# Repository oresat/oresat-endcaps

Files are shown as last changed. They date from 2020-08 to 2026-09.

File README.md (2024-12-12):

# "End Cap" PCBs for OreSat

These are the "end cap" PCBs that attach to the +Z and -Z ends of the satellites. Mostly these are to protect the end cards from "space", as well as to hold the magnetometers (two per end cap) as far as away from ferrous stuff as possible. It's also a good place for backup antennas, specifically patch antennas (S band and GPS L1).

## Features

- Cutouts for deployable antennas
- Double magnetometers.
- Single vertical 10mm tall 1.27 mm connector that plugs into the "end card" card.
    - On the End Cap:  Harwin M55-6001242R 12 pin female vertical connector 
    - On the End Card below: Harwin M55-7011242R 12 pin male vertical connector
- No available RF connectors.

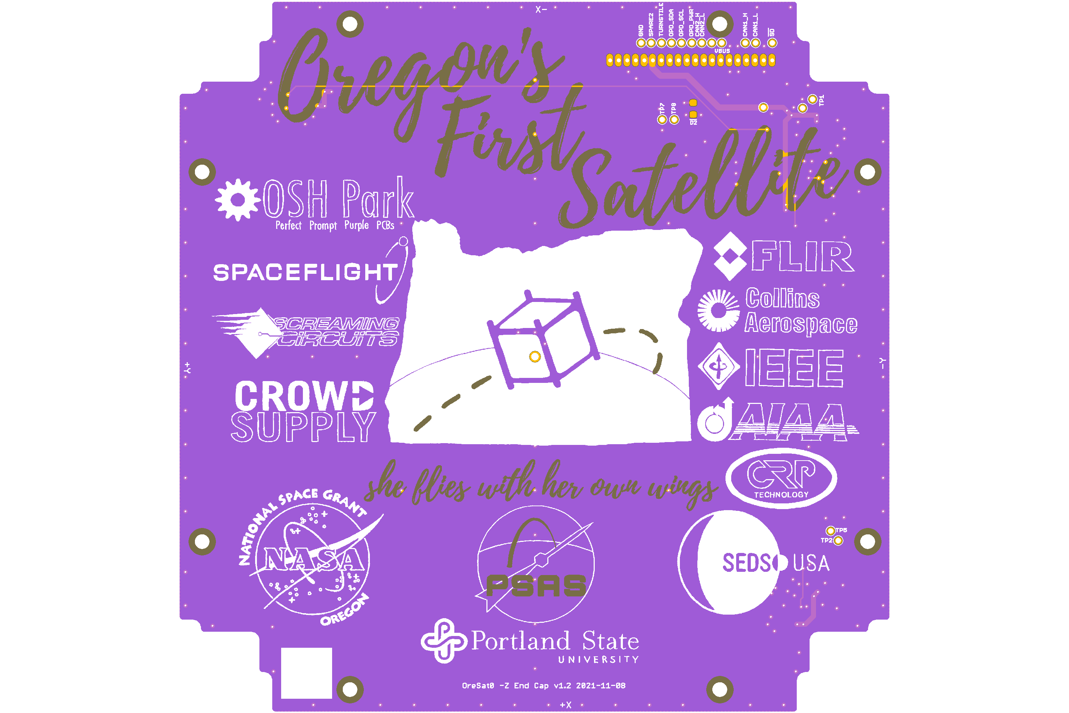
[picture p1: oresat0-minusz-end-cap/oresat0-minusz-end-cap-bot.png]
OreSat +Z End Cap Picture


## LICENSE

Copyright the Portland State Aerospace Society, 2024.

This source describes Open Hardware that is licensed under CERN-OHL-S v2, or any later version.

You may redistribute and modify this source and make products using it under the terms of the CERN-OHL-S v2 (https://ohwr.org/cern_ohl_s_v2.txt).

This source is distributed WITHOUT ANY EXPRESS OR IMPLIED WARRANTY, INCLUDING OF MERCHANTABILITY, SATISFACTORY QUALITY AND FITNESS FOR A PARTICULAR PURPOSE. Please see the CERN-OHL-S v2 for applicable conditions.

Source location: <https://github.com/oresat/>

As per CERN-OHL-S v2 section 4, should You produce hardware based on this source, You must where practicable maintain the Source Location visible on the external case of the Gizmo or other products you make using this source.

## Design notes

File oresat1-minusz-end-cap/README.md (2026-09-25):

---
title: "**OreSat1 -Z End Cap**"
subtitle: |
  **Fabrication and Assembly Information**\
  For build TIME-STAMP
fontsize: 10pt
geometry:
  - margin=0.5in
toc: true
toc-depth: 2
colorlinks: true
urlcolor: blue
---

\newpage

# About this Board

## Board Description

The OreSat1 -Z End Cap is the board that "caps" the -Z end of the OreSat1 satellite. It protects the -Z End Card and also carries two PNI RM3100 magnetometers, as far away from the internal OreSat magnetic noise as possible. 

## Documentation Links

- End cap hardware Git repository: <https://github.com/oresat/oresat-endcap>
- **TODO:** End Cap Design Notes + Design Review Notes

## Documentation Files

| Filename | Notes |
| --- | --- |
| README.pdf | This README file |
| PROJECT-NAME-outline.dxf | Board outline (with holes) in DXF format |
| PROJECT-NAME-pcba.step | 3D model of PCBA (with components) |
| PROJECT-NAME-render-bot.jpg | Render of the top of the 3D model |
| PROJECT-NAME-render-bot.jpg | Render of the bottom of the 3D model |
| PROJECT-NAME-schematic.pdf | PDF of board schematics |

## Contact Information

- Website: <https://www.oresat.org/>
- Email: <oresat@pdx.edu>
- Instagram: @pdxaerospace

## Board Renders

Render of the top of the 3D model
Render of the bottom of the 3D model

\newpage

# Printed Circuit Board (PCB) Fabrication Information

## Board Info

- 4 layer board
- Bounding box is 105.6 x 105.6 mm
- Board thickness is 1.59 mm (0.063 inch)

## Board Requirements

- Design Rules
    - Minimum Trace / Space design rules
       - Outer layers: 0.127 mm (5.0 mil) / 0.127 mm (5.0 mil)
       - Inner layers: 0.127 mm (5.0 mil) / 0.127 mm (5.0 mil)
    - Outer dimension router tolerance: +/- 0.254 mm (10.0 mil)
    - Hole placement tolerance: +/- 0.075 mm (3.0 mil)
    - Inner tab routed slot tolerance: +/- 0.254 mm (10.0 mil)
- Drills
   - Drill Positional Tolerance: 0.051 mm (2.0 mil)
   - Drill Size tolerance: +/- 0.064 mm (2.5 mil)
- Plated/Un-plated holes
  - There are 11 un-plated (NPT) holes
  - PTH minimum diameter: 0.254 mm (10 mil)
  - PTH minimum annulus: 0.102 mm (4 mil) radius
- Outline/Routing
  - Requires a 1.0 mm or smaller diameter routing bit
- Slots
  - There are no slots.
- Cutouts
  - There is one cutout.
- There are 3 fiducials on the top layer and 3 fiducials on the bottom layer.
- Panel tabs ("mouse bites")
   - Card edges must be smooth; no mouse bites or other intrusions into the card outline.
   - If external mouse bites are required, minimize and customer will remove by hand before assembly.
- If not otherwise specified, build to IPC 6012 Class 2 or better.

## Materials

- No controlled impedance.
- Outer layers must be 1 oz Copper, inner layers can be 0.5 or 1.0 oz Copper.
- Isola FR408HR or material recommended.
- Board Surface treatment should be ENIG, althogh immersion Silver is acceptable.
- White silkscreen on top and bottom surface
- Taiyo PSR-4000 or equivalent soldermask on top and bottom, no requirements for color.

## Suggested Stack Up

| Layer | Thickness | Notes |
|---|---|---|
| Top Copper | 0.043 mm /  1.7 mil |  Layer 1 foil, 1 oz Cu after plating |
| prepreg | 0.200 mm /  7.9 mil |  Prepreg - Isola FR408HR 2113 |
| Layer 2 | 0.018 mm /  0.7 mil |  Layer 2 foil, 0.5 oz Cu |
| Core | 0.991 mm / 39 mil |  Core Isola FR408HR |
| Layer 3 | 0.018 mm /  0.7 mil |  Layer 3 foil, 0.5 oz Cu |
| prepreg | 0.200 mm /  7.9 mil |  Prepreg - Isola FR408HR 2113 |
| Bottom Copper | 0.043 mm /  1.7 mil |  Layer 4 foil, 1 oz copper after plating |
| **Total Stackup** | **1.588 mm / 62.5 mil** | |

## Array / Panel Information

- Coordinate with Contract Manufacturer (CM) for optimal size of this panel.
- If no feedback from CM, then produce single boards (no panel).

## Fabrication Files

### IPC-2581 File

| Filename | Notes |
| --- | --- |
| PROJECT-NAME-ipc2581.xml | IPC-2581 board information file |

### Legacy PCB Files

| Filename | Notes |
| ---| --- |
| PROJECT-NAME-Edge_Cuts.gbr | RS274X file for the dimension (outline) layer |
| PROJECT-NAME-F_Silkscreen.gbr | RS274X file for the top silkscreen |
| PROJECT-NAME-F_Mask.gbr | RS274X file for the top soldermask |
| PROJECT-NAME-F_Cu.gbr | RS274X file for the top copper layer |
| PROJECT-NAME-In1_Cu.gbr | RS274X file for the layer 2 copper |
| PROJECT-NAME-In2_Cu.gbr | RS274X file for the layer 3 copper |
| PROJECT-NAME-B_Cu.gbr | RS274X file for the bottom copper layer |
| PROJECT-NAME-B_Mask.gbr | RS274X file for the bottom soldermask |
| PROJECT-NAME-B_Silkscreen.gbr | RS274X file for the bottom silkscreen |
| PROJECT-NAME-NPTH.drl | Excellon file for non-plated through holes |
| PROJECT-NAME-PTH.drl | Excellon file for plated through holes | 

\newpage

# Printed Circuit Board Assembly (PCBA) Information

## Assembly Info

- There are components on the top and bottom side of the board.
- This PCBA is mostly surface mount (SMT).

## Assembly Requirements

- Assemble to IPC Class 2 or better
- Bake components that are not moisture sealed to appropriate levels as required.
- Solder paste MUST be leaded.
- Aqueous flux and wash strongly preferred.
   - Clean to NASA Standard "Visibly Clean (VC)": No particles or residues are visible to the naked eye.
- No conformal coating.
- Ship in antistatic protective bag

## Component Specific Assembly Information

- No specific requirements.

## Assembly Files

### IPC-2581 File

| Filename | Notes |
| --- | --- |
| PROJECT-NAME-ipc2581.xml | IPC-2581 board information file |

### Bill of Materials (BOM)

| Filename | Description |
| --- | --- |
| PROJECT-NAME-bom.csv | BOM in Comma Separated Variable format |

### Solder Paste Stencils

| Filename | Notes |
| --- | --- |
| PROJECT-NAME-B_Paste.gbr | RS274X file for top/front solder paste stencil |
| PROJECT-NAME-F_Paste.gbr | RS274X file for bottom/back solder paste stencil |

### Mounting/Placement Location

| Filename | Description |
| --- | --- |
| PROJECT-NAME-3u.pos | Pick and place locations for components |

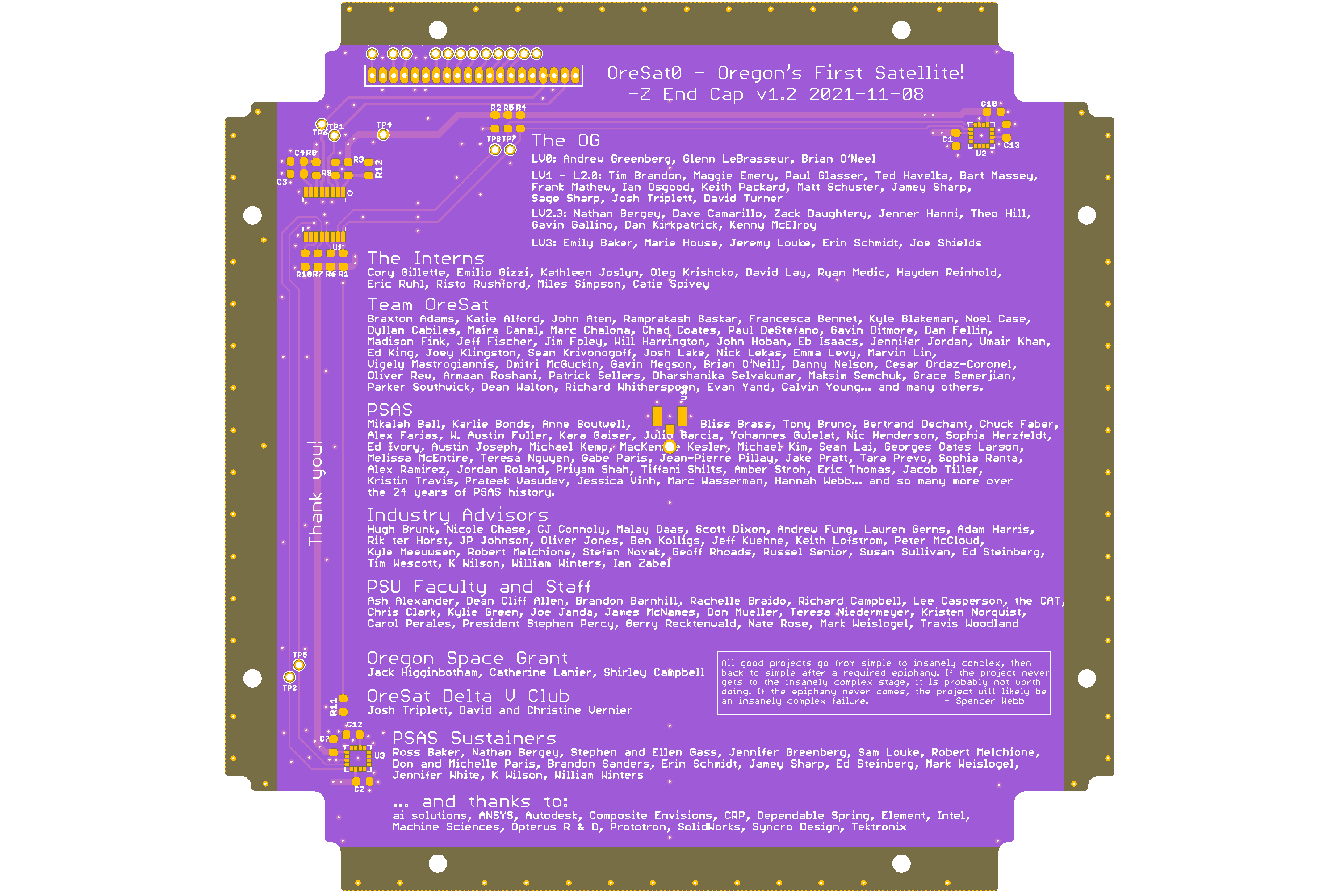
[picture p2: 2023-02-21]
oresat0-minusz-end-cap/oresat0-minusz-end-cap-top.png

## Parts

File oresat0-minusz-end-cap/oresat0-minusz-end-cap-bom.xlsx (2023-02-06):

Bill Of Materials (BOM) for OreSat0 -Z End Cap
PCB version: 1.2 |  |  |  | Assembly options: P/NP/NPFF/TH = Place/No Place/No Place For Flight/Through-Hole
BOM revision: 0 |  |  |  | Generic: Y = Any part with the same characteristics may be substituted
Cnt | Part References | Assembly | Mfg | Mfg PN | Description | Generic | Dist. | Dist. PN | Stock | Cost | Ext. | Notes
1 | ANT1 | P | Linx Tech. | ANT-2.4-CPA | 2.45Ghz Ceramic Patch RF Antenna 2.4Ghz ~ 2.5Ghz 5.5dBi Pin Adhesive | N | Digi-Key | 343-ANT-2.4-CPA-ND | 3 | $3.80 | $3.80 | OreSat0 only, for DxWiFi test
5 | C1, C2, C3, C7, C10 | P | Taiyo Yuden | TMK107BJ104KAHT | 0.1µF ±10% 25V Ceramic Capacitor X5R 0603 (1608 Metric) | Y | Digi-Key | 587-3472-1-ND | 0 | $0.10 | $0.50
3 | C4, C12, C13 | P | Murata Electronics | GRT188R61A106KE13D | 10 µF ±10% 10V Ceramic Capacitor X5R 0603 (1608 Metric) | Y | Digi-Key | 490-12311-1-ND | 0 | $0.44 | $1.32
1 | D2 | NP FF | Rohm | SML-E12M8WT86 | LED GREEN DIFFUSED 0603 SMD | Y | Digi-Key | 511-1584-1-ND | 0 | $0.31 | $0.31
1 | J1 | TH | TE Connectivity | 6-104178-1 | CONN HEADER VERT 20POS 1.27MM | N | Digi-Key | A122888-ND | 8 | $3.36 | $3.36
2 | R11, R12 | NP | NP | NP | NP | NP | NP | NP | NP | NP | NP
10 | R1, R2, R3, R4, R5, R6, R7, R8, R9, R10 | P | TE Connectivity | CRGCQ0603F4K7 | CRGCQ Resistor 0603 4K7 1% | Y | Digi-Key | A129696CT-ND | 0 | $0.10 | $1.00 | R2 NPFF, although fine if placed.
1 | U1 | P | Analog Devices | LTC4305IGN#PBF | 2 Channel I2C Bus Multiplexer | N | Digi-Key | LTC4305IGN#PBF-ND | 3 | $8.05 | $8.05
2 | U2, U3 | P | Memsic | MMC5883MA | Magnetoresistive Sensor X, Y, Z Axis 16-LGA (3x3) | N | Digi-Key | 1267-1072-1-ND | 0 | $6.51 | $13.02 | Magnetometers
 |  |  |  |  |  |  |  | TOTAL |  |  | $31.36
VERSION INFO
Rev | Date | Notes
1.2r0 | 2021-11-10 | Added S band patch; cleaned up BOM.
1.0r0 | 2020-08-28 | First version of BOM

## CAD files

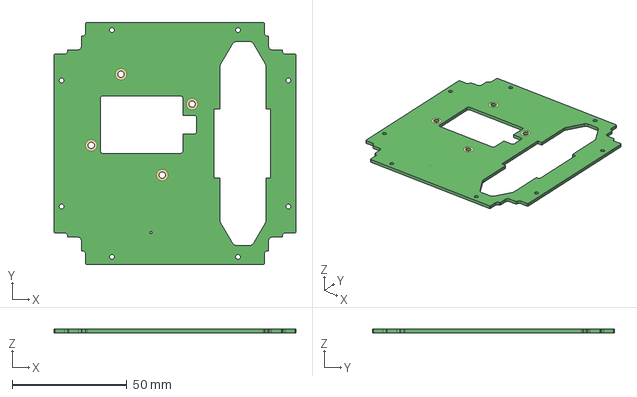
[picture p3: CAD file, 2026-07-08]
esi-minusz-end-cap/-Z EndCap.stp
105.6 x 105.6 x 1.60 mm

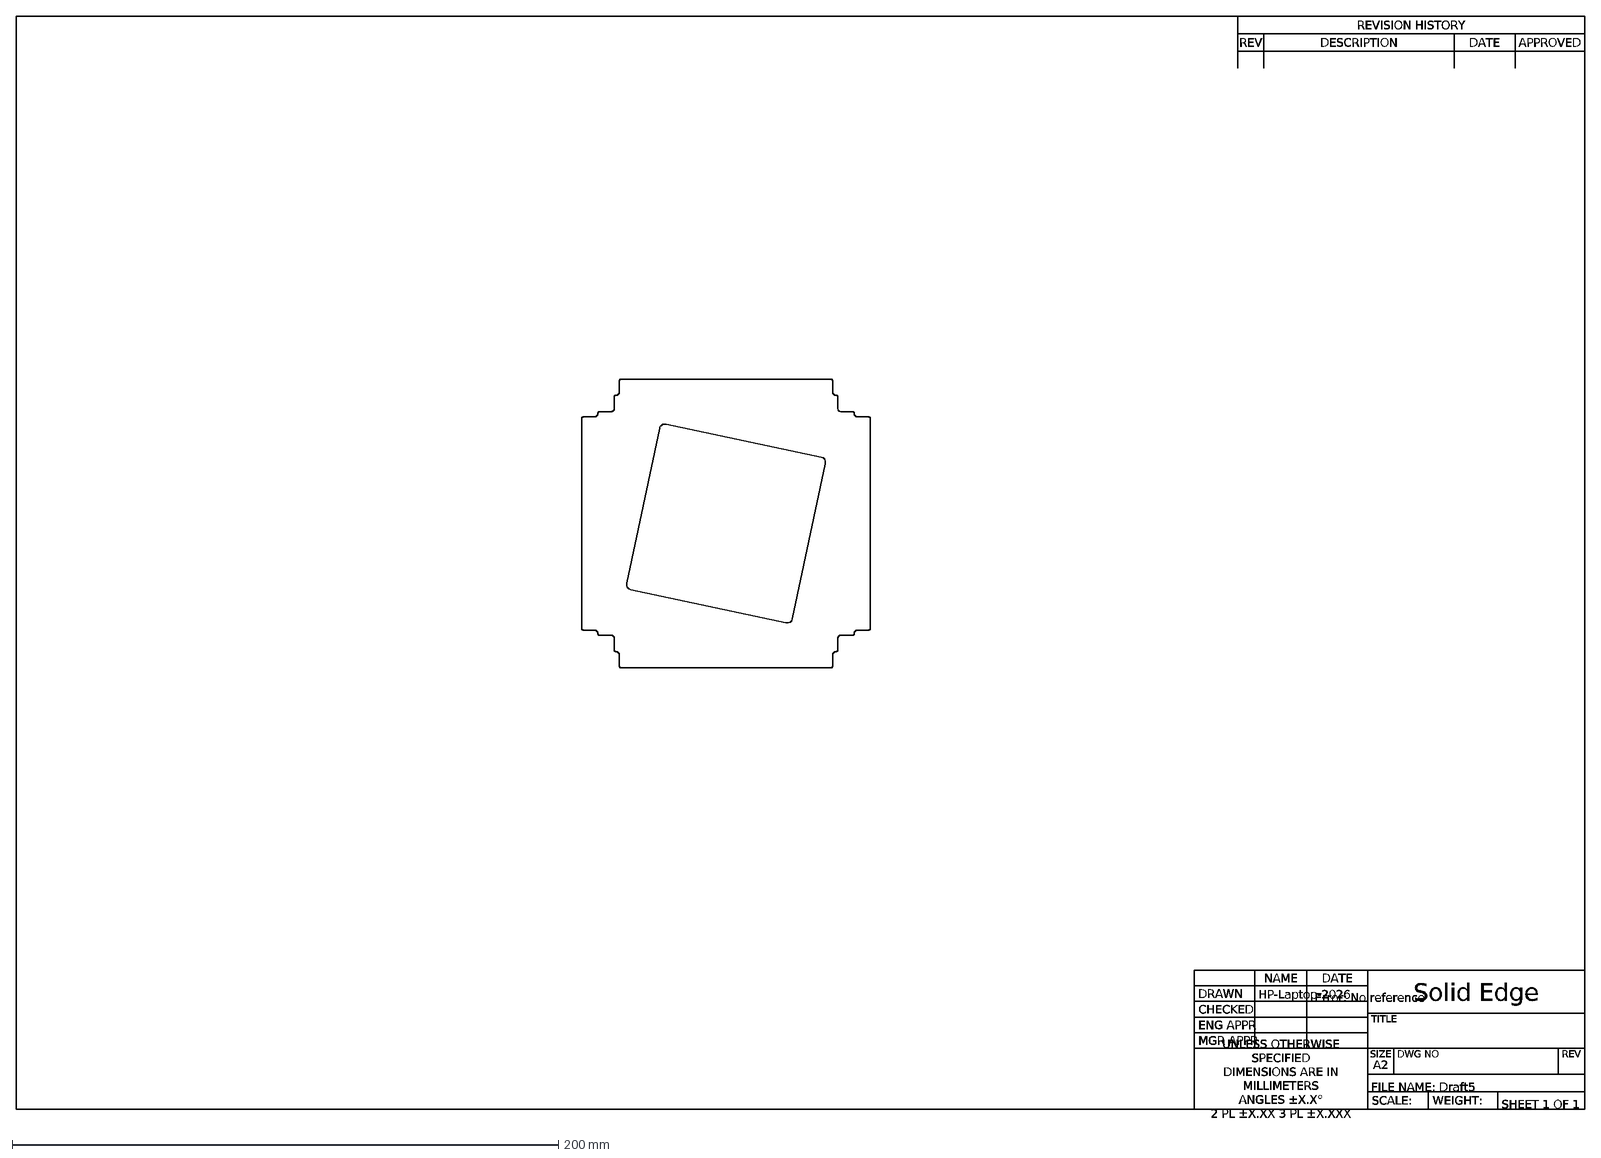
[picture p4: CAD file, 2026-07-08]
esi-plusz-end-cap/Beecon +Z End Cap (for dxf).dxf
DRAWN
CHECKED
ENG APPR
MGR APPR
UNLESS OTHERWISE SPECIFIED DIMENSIONS ARE IN MILLIMETERS ANGLES ±X.X° 2 PL ±X.XX 3 PL ±X.XXX
NAME
HP-Laptop-2026
DATE
Error: No reference
Solid Edge
TITLE
SIZE
A2
DWG NO
REV
FILE NAME: Draft5
SCALE:
WEIGHT:
SHEET 1 OF 1
REVISION HISTORY
DESCRIPTION
APPROVED

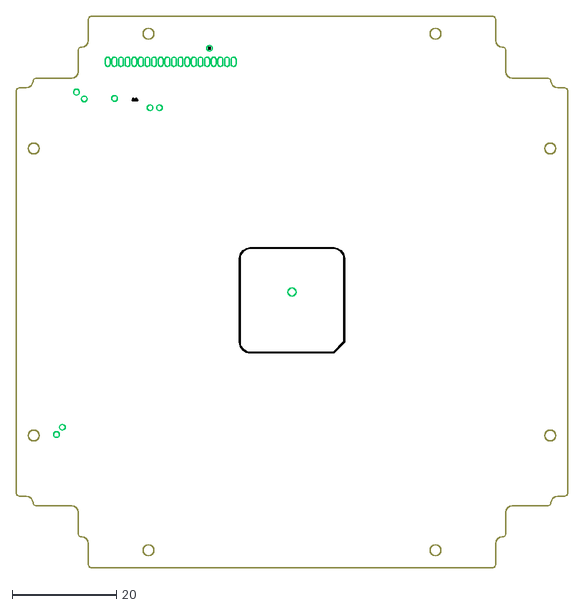
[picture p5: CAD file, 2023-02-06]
oresat0-minusz-end-cap/oresat0-minusz-end-cap.dxf
105.6 x 105.6

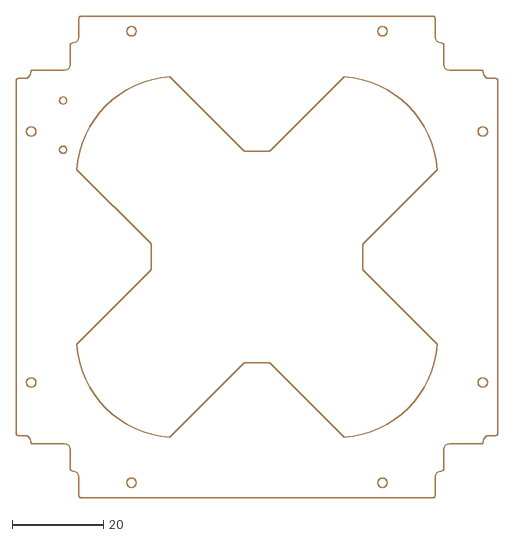
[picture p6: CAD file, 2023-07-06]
oresat0-plusz-end-cap/oresat0-plusz-end-cap.dxf
105.6 x 105.6

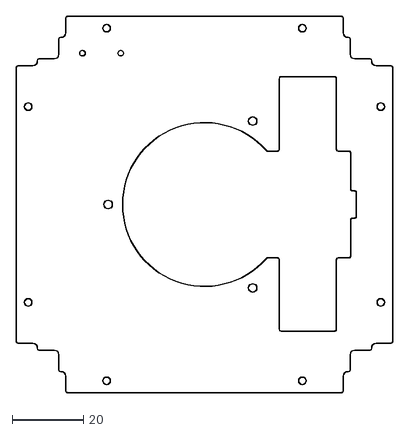
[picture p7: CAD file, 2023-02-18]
oresat0.5-minusz-end-cap/minusz-end-cap.dxf
105.6 x 105.6

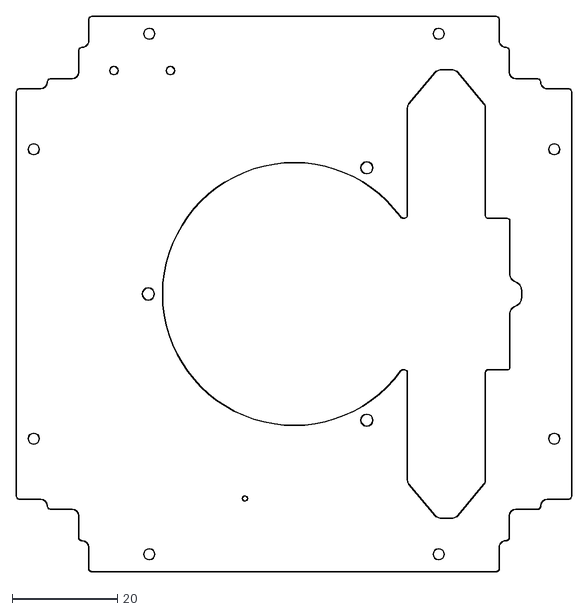
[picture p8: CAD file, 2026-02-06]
oresat1-minusz-end-cap/OreSat1 -Z End Cap DXF.dxf
105.6 x 105.6

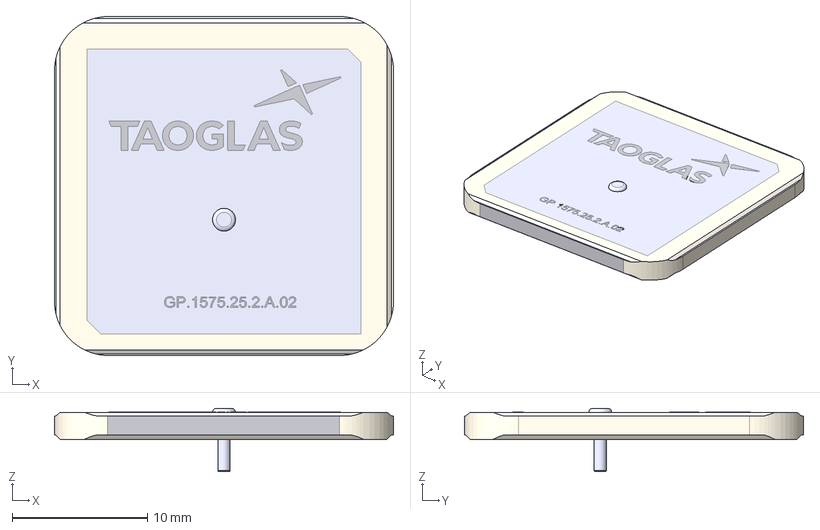
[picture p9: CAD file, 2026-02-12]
oresat1b-minusz-end-cap/GPS Antenna.step
25.1 x 25.1 x 4.70 mm

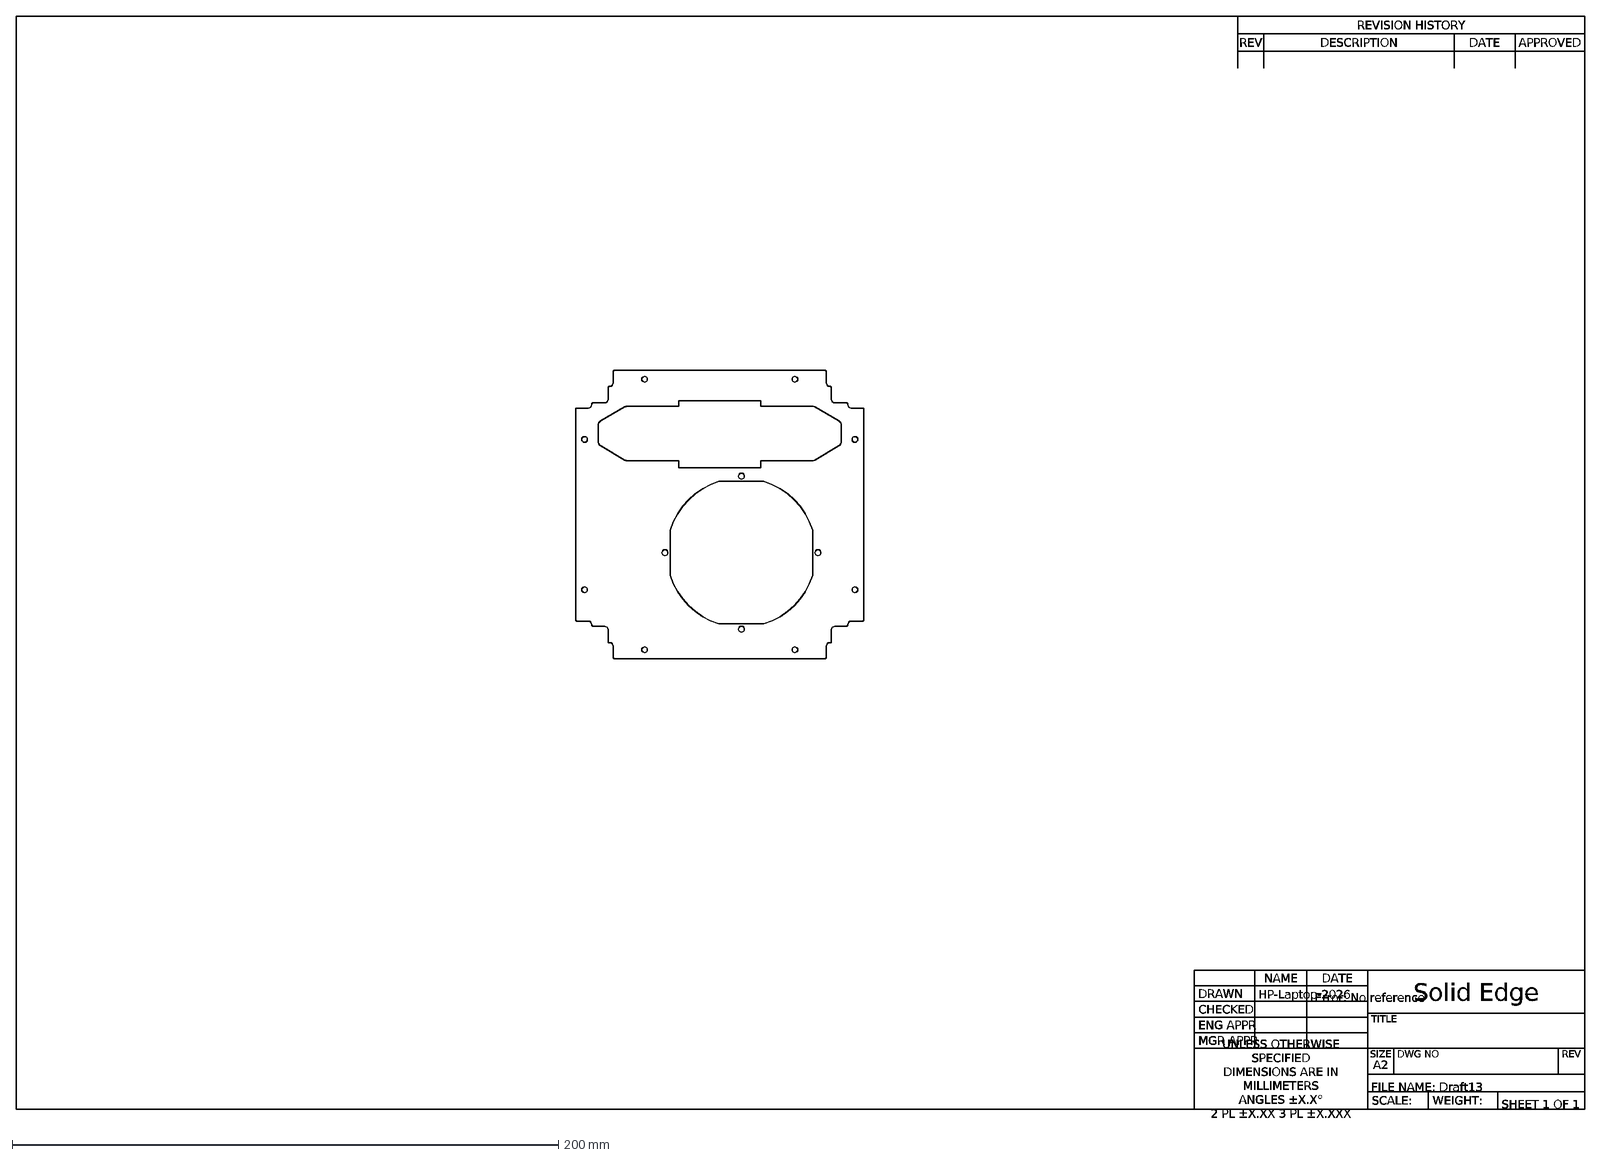
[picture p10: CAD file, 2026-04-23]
esi-minusz-end-cap/esi-mZ-end-cap-drawing.dxf
DRAWN
CHECKED
ENG APPR
MGR APPR
UNLESS OTHERWISE SPECIFIED DIMENSIONS ARE IN MILLIMETERS ANGLES ±X.X° 2 PL ±X.XX 3 PL ±X.XXX
NAME
HP-Laptop-2026
DATE
Error: No reference
Solid Edge
TITLE
SIZE
A2
DWG NO
REV
FILE NAME: Draft13
SCALE:
WEIGHT:
SHEET 1 OF 1
REVISION HISTORY
DESCRIPTION
APPROVED

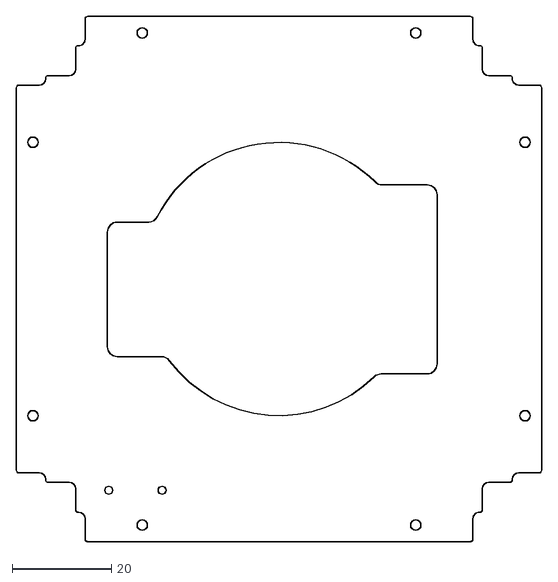
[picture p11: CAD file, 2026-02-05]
esi-plusz-end-cap/esi-plusz-end-cap.dxf
105.6 x 105.6

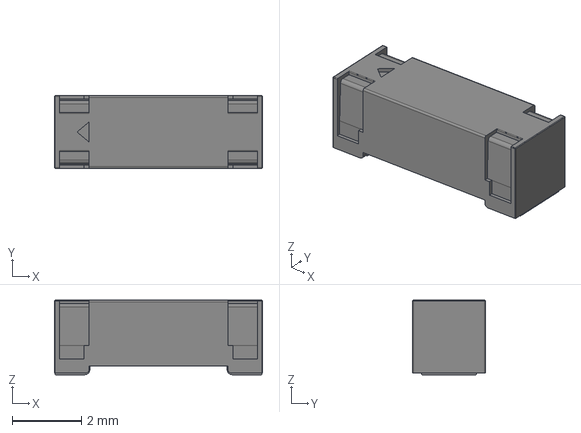
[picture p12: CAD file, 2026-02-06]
esi-minusz-end-cap/rm3100-geomagnetic-sensor-1.snapshot.5/13104.stp
6.00 x 2.10 x 2.15 mm
13104_body
13104_pin x 2

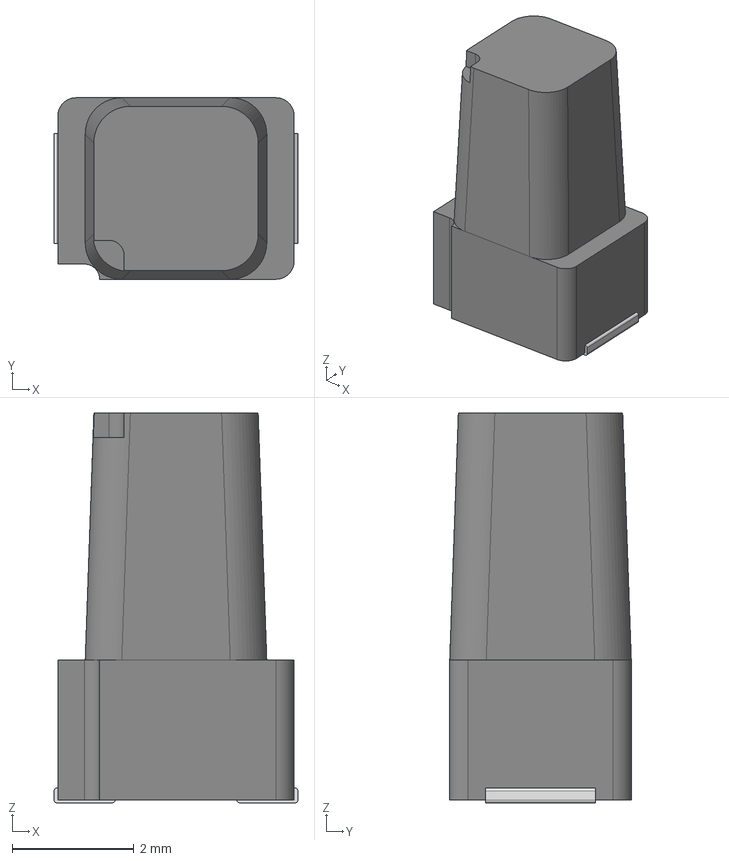
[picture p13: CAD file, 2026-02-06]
esi-minusz-end-cap/rm3100-geomagnetic-sensor-1.snapshot.5/13101.stp
4.00 x 2.98 x 6.40 mm
13101_body
13101_pin x 2

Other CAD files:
esi-minusz-end-cap/-Z EndCap.dxf

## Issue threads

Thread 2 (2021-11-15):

+/- Z end cap stop layer against frames is wrong

andrewgreenberg, 2021-11-15:
Currently it's 5 mm  on X and 6 mm on Y. Check that:

- The PCB outline has at least 0.2 mm of clearance on all edges when centered on the frame.
- The frames are current 5.4 mm thick at the end caps. The PCB is 0.2 mm clearance between the PCB outline and the edge of the frames. Assuming that the end caps can shift quite a bit since only the fasteners locate them, like 0.2 mm, then stop mask against the frames should be at least 5.4 mm on all axes.

andrewgreenberg, 2024-04-08:
Fixed on all modern end caps; closing issue for old eagle cad end caps.

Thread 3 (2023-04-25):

-Z endcap needs stop mask removed below M2 fastener heads

andrewgreenberg, 2023-04-25:

andrewgreenberg, 2023-04-25:
Check the +Z too

andrewgreenberg, 2024-04-08:
Fixed on all modern end caps; closing issue for old eagle cad end caps.

Closed 2024-04-08.

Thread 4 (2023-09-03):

Fix missing pin errors on MMC5883

andrewgreenberg, 2023-09-03:
There are missing net errors on the PCB, so make sure the symbol has all of the pins even if hidden.

JackkP, 2024-03-20:
Resolved with update to MMC5983 connector resolved with commit #91e2a84bc3bbfb4f4b00fdec69fde92a316cd931

Closed 2024-03-20.

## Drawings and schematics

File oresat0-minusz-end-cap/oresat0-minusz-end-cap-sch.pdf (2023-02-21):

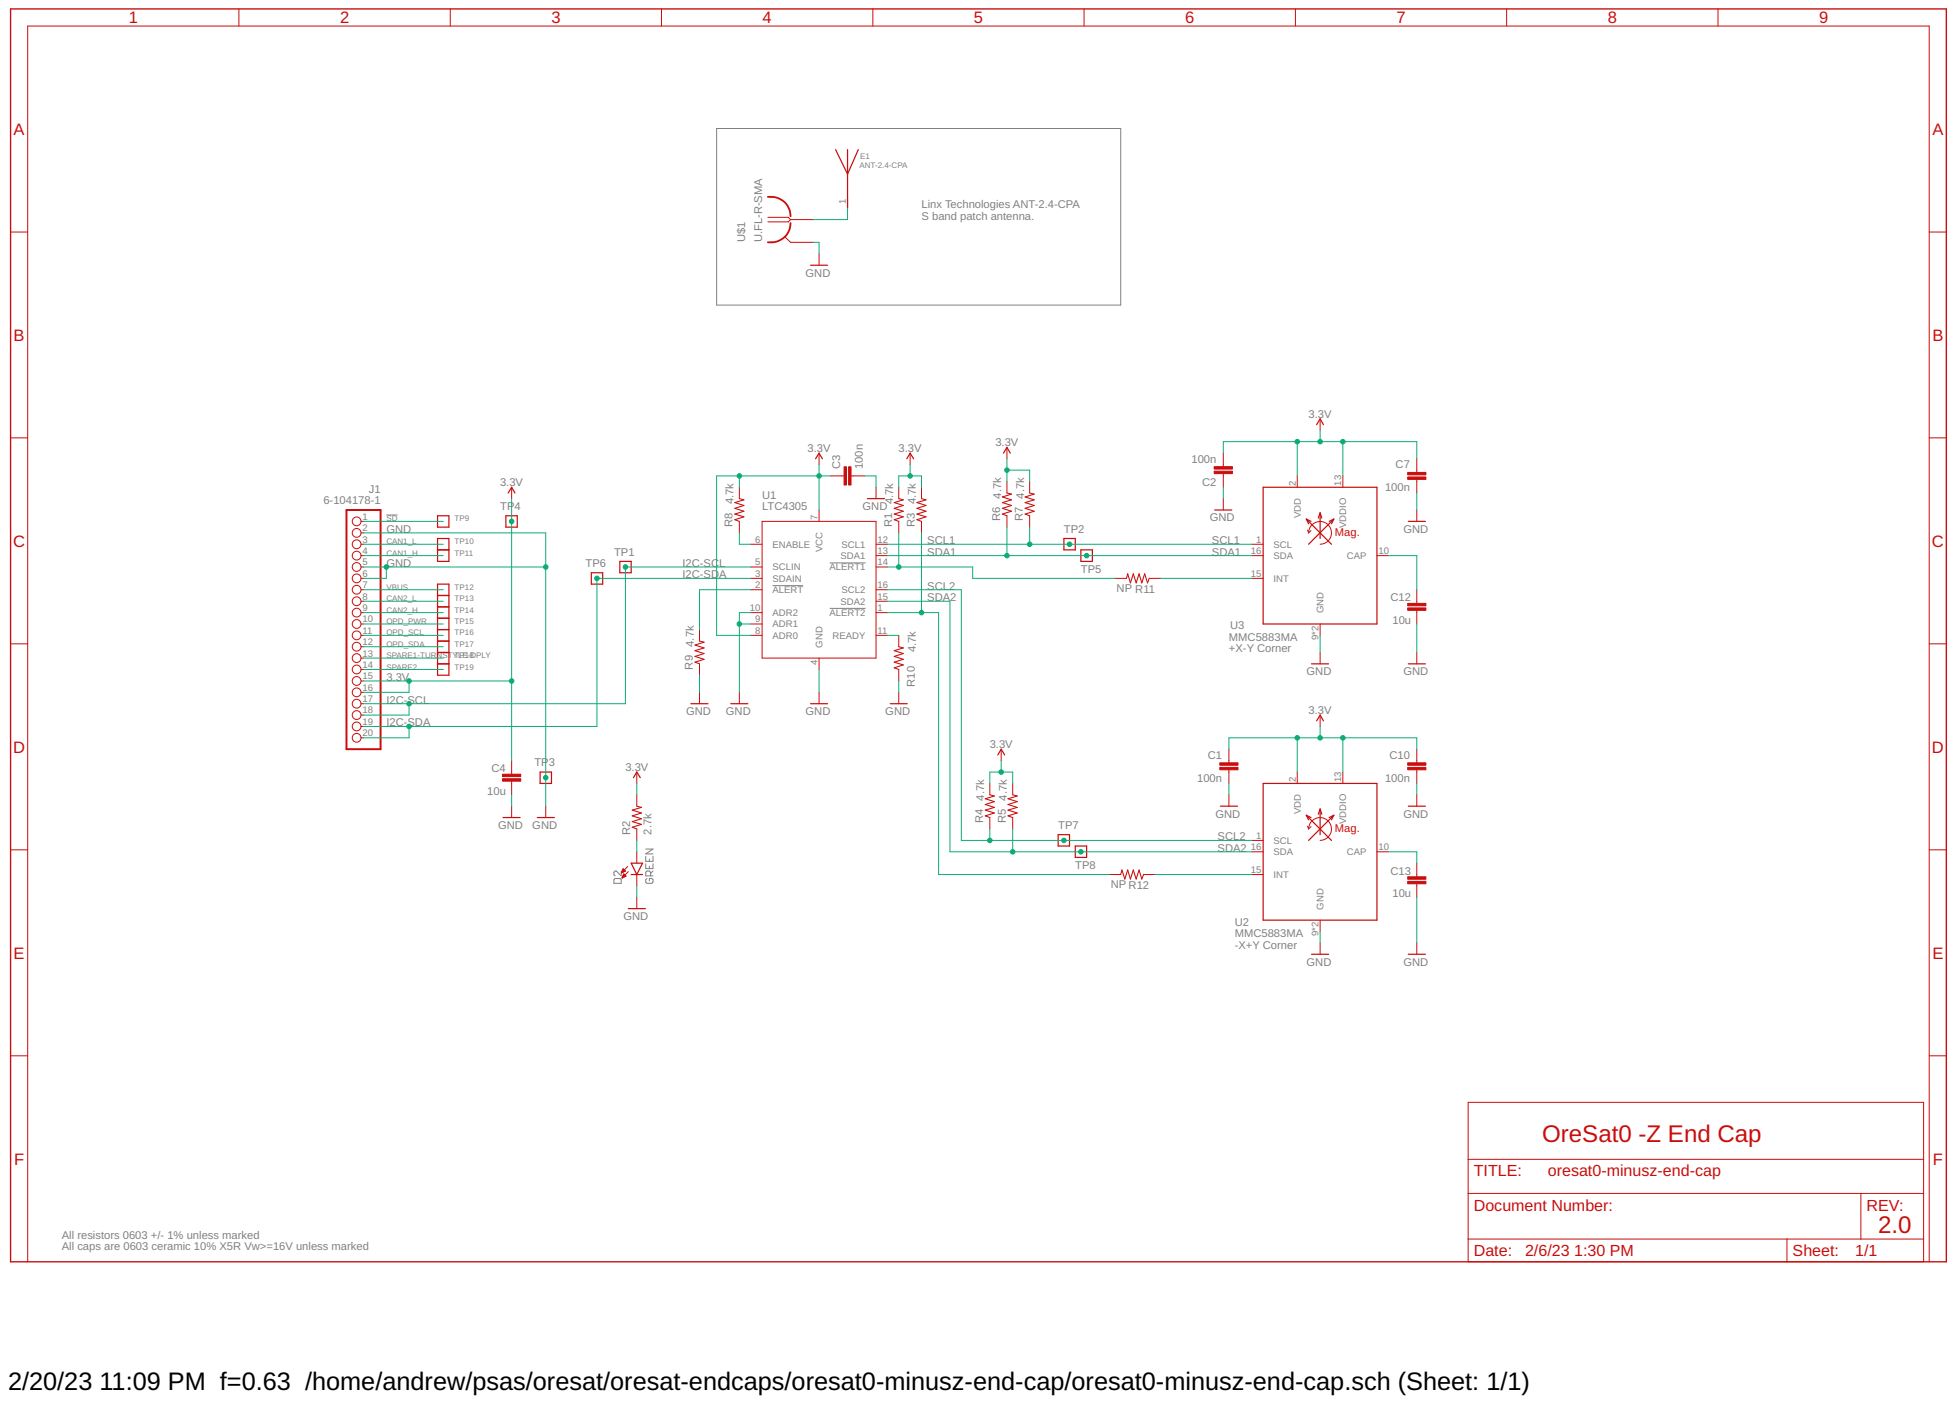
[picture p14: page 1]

Linx Technologies ANT-2.4-CPA
S band patch antenna.

SDA2

All resistors 0603 +/- 1% unless marked All caps are 0603 ceramic 10% X5R Vw>=16V unless marked

2/20/23 11:09 PM f=0.63 /home/andrew/psas/oresat/oresat-endcaps/oresat0-minusz-end-cap/oresat0-minusz-end-cap.sch (Sheet: 1/1)

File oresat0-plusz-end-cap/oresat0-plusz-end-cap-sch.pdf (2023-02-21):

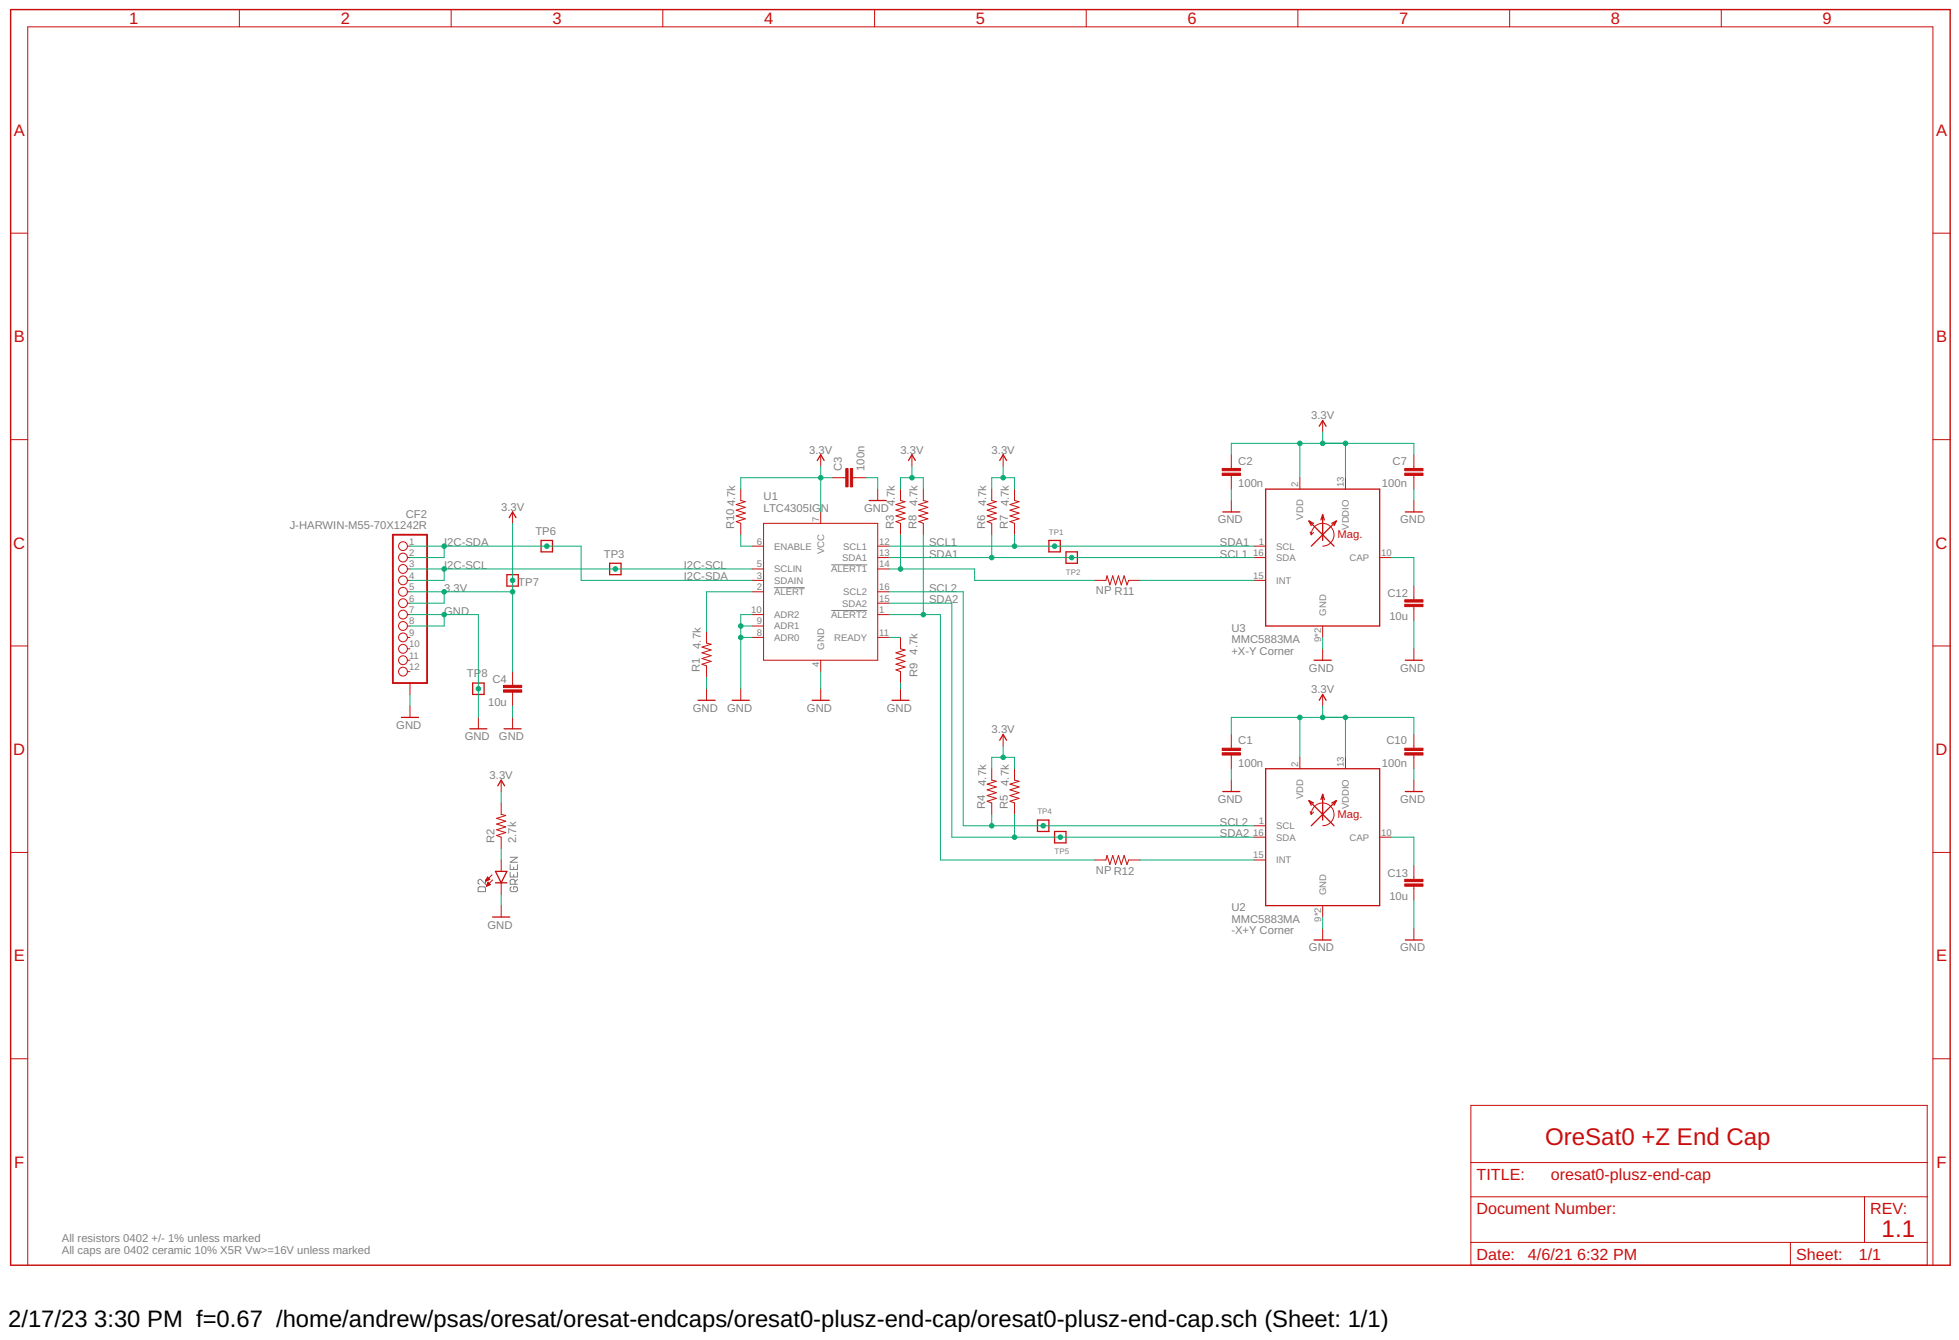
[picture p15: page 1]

All resistors 0402 +/- 1% unless marked All caps are 0402 ceramic 10% X5R Vw>=16V unless marked

2/17/23 3:30 PM f=0.67 /home/andrew/psas/oresat/oresat-endcaps/oresat0-plusz-end-cap/oresat0-plusz-end-cap.sch (Sheet: 1/1)

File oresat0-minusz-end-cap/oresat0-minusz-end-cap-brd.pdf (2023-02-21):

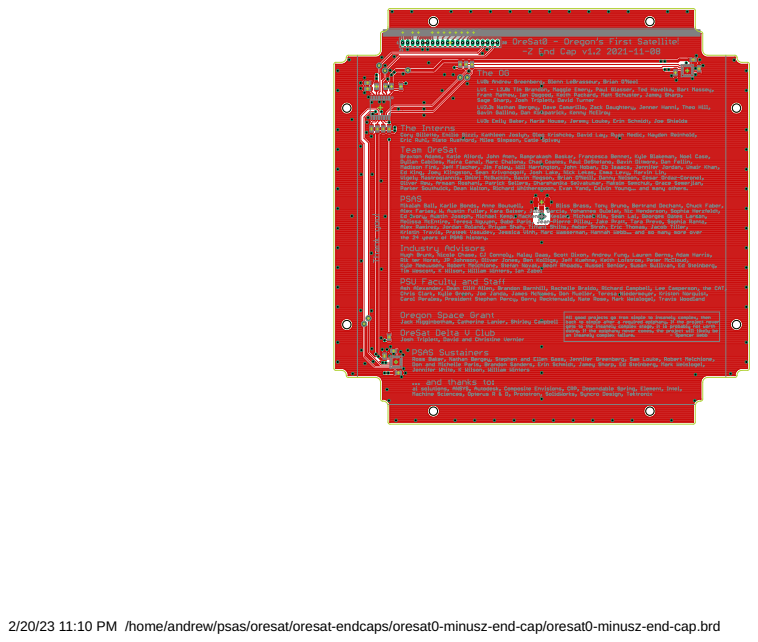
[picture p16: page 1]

2/20/23 11:10 PM /home/andrew/psas/oresat/oresat-endcaps/oresat0-minusz-end-cap/oresat0-minusz-end-cap.brd

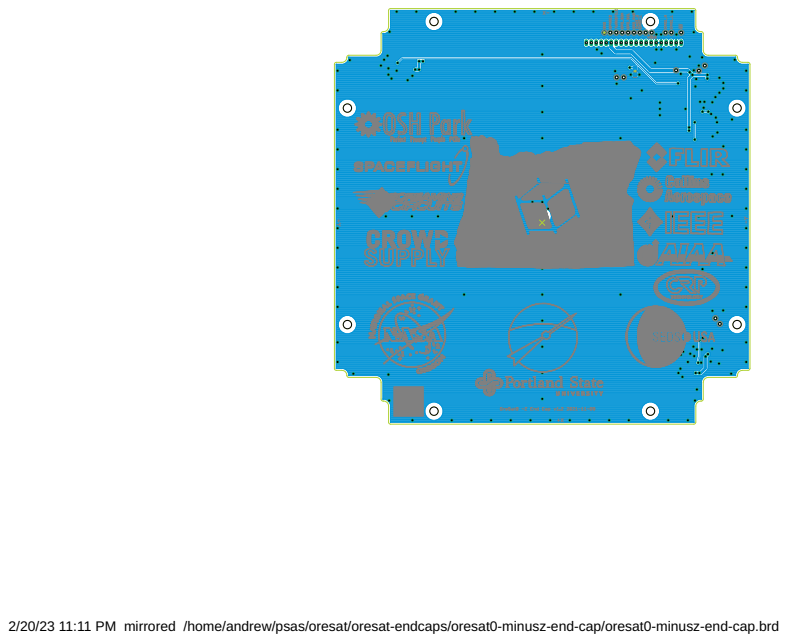
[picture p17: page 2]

2/20/23 11:11 PM mirrored /home/andrew/psas/oresat/oresat-endcaps/oresat0-minusz-end-cap/oresat0-minusz-end-cap.brd

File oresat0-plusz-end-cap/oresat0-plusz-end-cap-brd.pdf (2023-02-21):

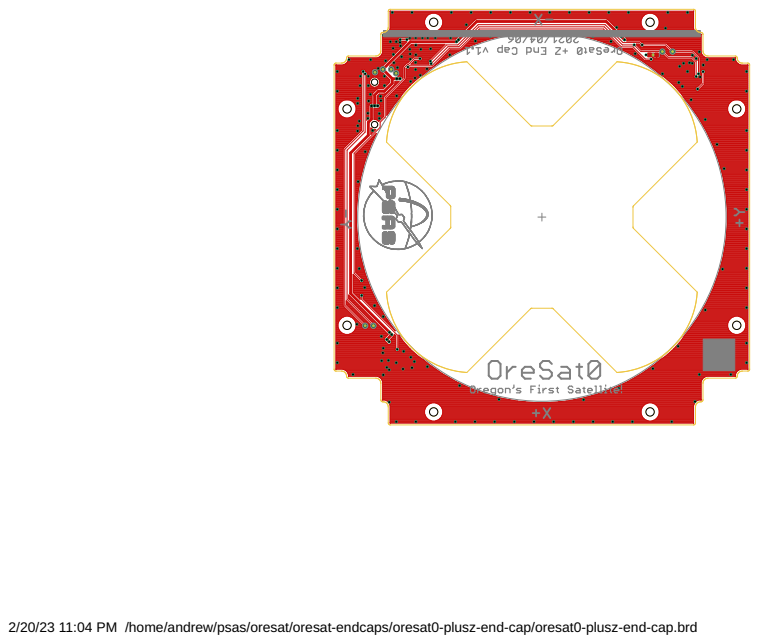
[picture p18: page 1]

2/20/23 11:04 PM /home/andrew/psas/oresat/oresat-endcaps/oresat0-plusz-end-cap/oresat0-plusz-end-cap.brd

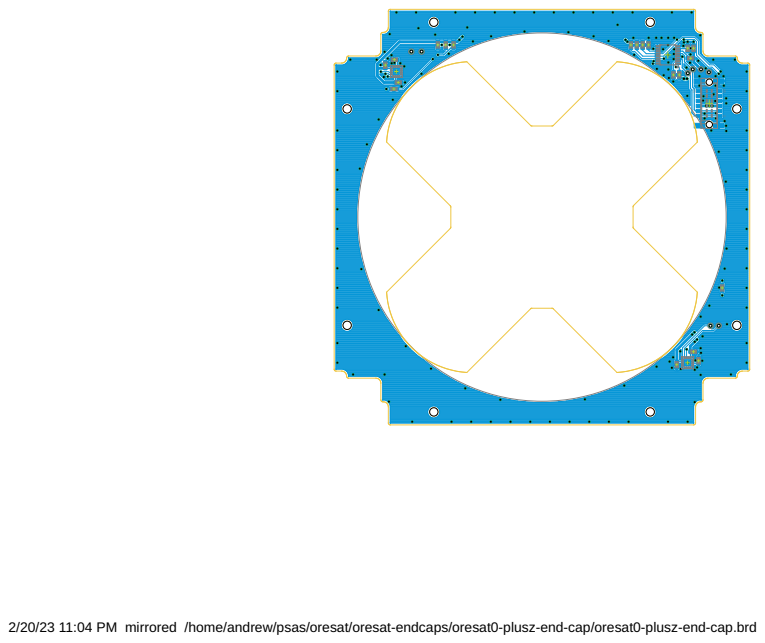
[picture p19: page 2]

2/20/23 11:04 PM mirrored /home/andrew/psas/oresat/oresat-endcaps/oresat0-plusz-end-cap/oresat0-plusz-end-cap.brd

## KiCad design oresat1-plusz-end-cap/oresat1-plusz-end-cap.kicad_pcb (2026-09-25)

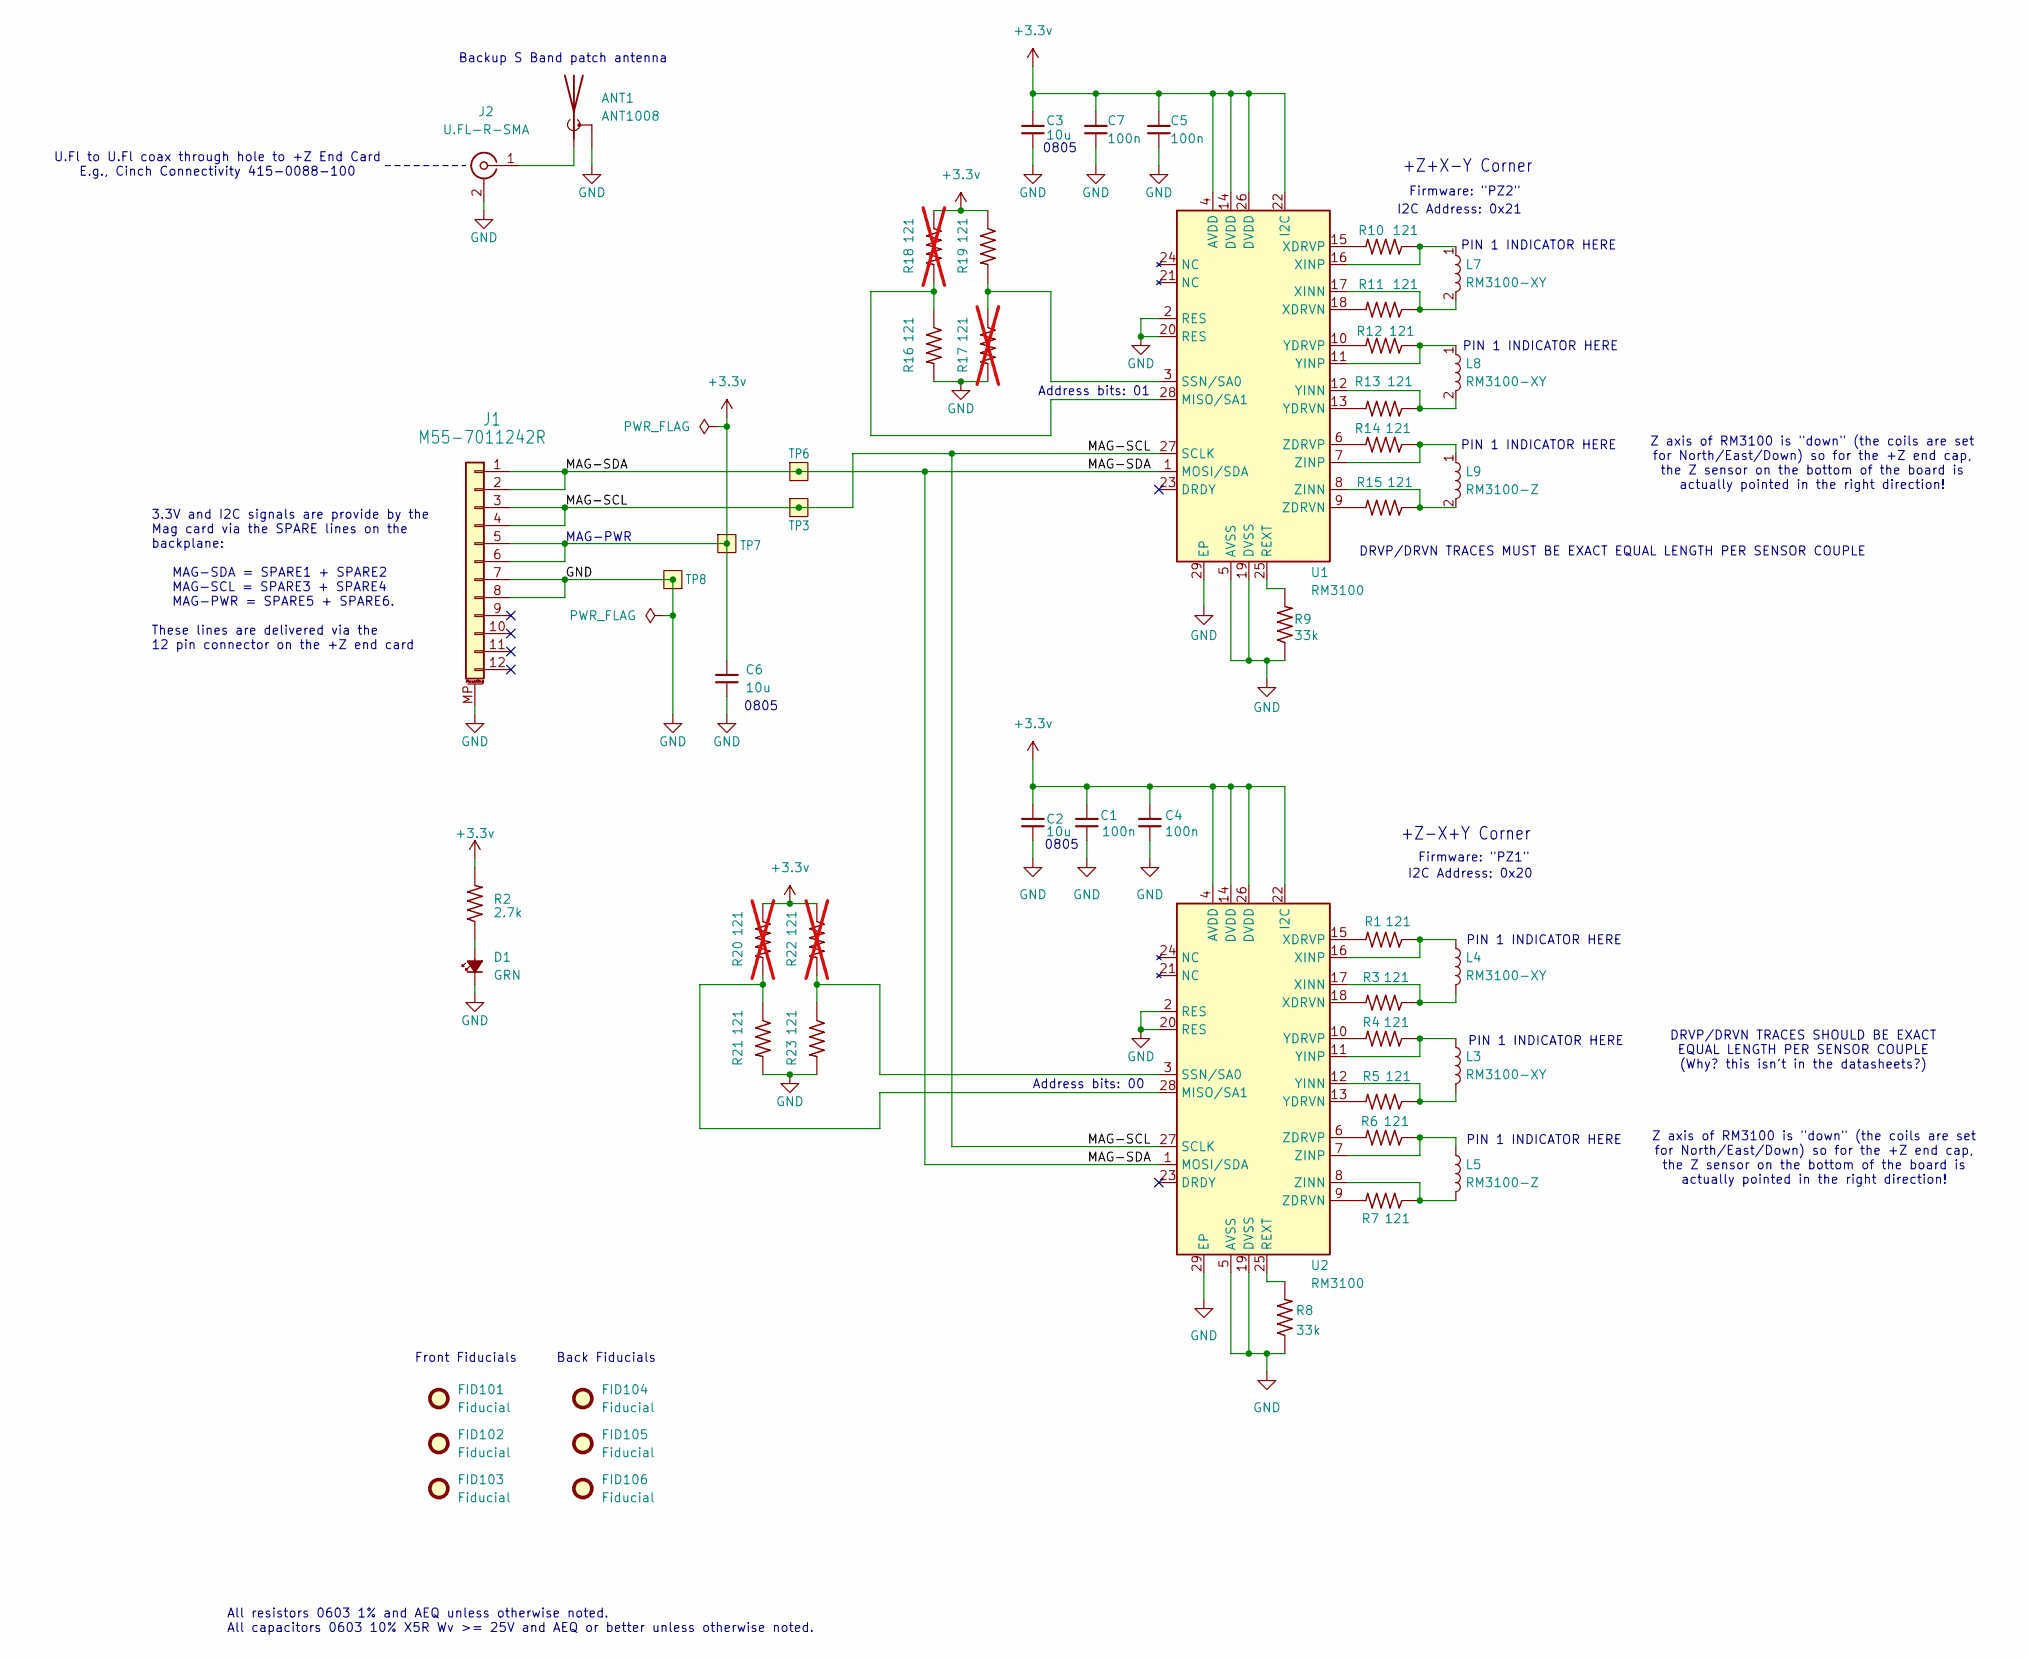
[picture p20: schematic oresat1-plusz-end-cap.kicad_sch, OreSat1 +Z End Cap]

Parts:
ANT1: ANT1008; RFMi-ANT1008-S-Band-Patch; MPN ANT1008
C1, C4, C5, C7: 100n; 0603-C-NOSILK; MPN C0603C104K5RACAUTO
C2, C3, C6: 10u; 0805-C-NOSILK; MPN GRT21BC71E106KE13K
D1: GRN; LED_0603_1608Metric; MPN 150060GS75000
FID101, FID102, FID103, FID104, FID105, FID106: Fiducial; Fiducial_1mm_Mask2mm
J1: M55-7011242R; J-Harwin-M55-7XX1242R; MPN M55-7011242R
J2: U.FL-R-SMA; U.FL_Hirose_U.FL-R-SMT-1_Vertical; MPN U.FL-R-SMT-1(10)
L3, L4, L7, L8: RM3100-XY; RM3100 SEN-XY-f; MFR PNI Sensors
L5, L9: RM3100-Z; RM3100 SEN-Z-f; MFR PNI Sensors
R1, R3, R4, R5, R6, R7, R10, R11, R12, R13, R14, R15, R16, R19, R21, R23: 121; 0603-C-NOSILK; MPN RMCF0603FT121R
R2: 2.7k; 0603-C-NOSILK; MPN RMCF0603FT2K70
R8, R9: 33k; 0603-C-NOSILK; MPN RMCF0603FT33K0
R17, R18, R20, R22: 121; 0603-C-NOSILK; MPN RMCF0603FT121R; not fitted
TP3, TP6, TP7, TP8: Test-Point; TestPoint-0.75mm-th; MPN N/A
U1, U2: RM3100; U-PNI-RM3100-IC; MFR PNI Sensors

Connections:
+3.3v: C1.1, C2.1, C3.1, C4.1, C5.1, C6.1, C7.1, J1.5, J1.6, R2.2, R18.1, R19.1, R20.1, R22.1, TP7.1 (1_1), U1.4 (AVDD), U1.14 (DVDD), U1.22 (I2C), U1.26 (DVDD), U2.4 (AVDD), U2.14 (DVDD), U2.22 (I2C), U2.26 (DVDD)
/MAG-SCL: J1.3, J1.4, TP3.1 (1_1), U1.27 (SCLK), U2.27 (SCLK)
/MAG-SDA: J1.1, J1.2, TP6.1 (1_1), U1.1 (MOSI/SDA), U2.1 (MOSI/SDA)
GND: ANT1.2 (Shield), C1.2, C2.2, C3.2, C4.2, C5.2, C6.2, C7.2, D1.1 (K), J1.7, J1.8, J1.MP (MountPin), J2.2 (Ext), R8.1, R9.1, R16.2, R17.2, R21.2, R23.2, TP8.1 (1_1), U1.2 (RES), U1.5 (AVSS), U1.19 (DVSS), U1.20 (RES), U1.29 (EP), U2.2 (RES), U2.5 (AVSS), U2.19 (DVSS), U2.20 (RES), U2.29 (EP)
unnamed: ANT1.1 (A), J2.1 (In)
unnamed: D1.2 (A), R2.1
unnamed: R16.1, R18.2, U1.28 (MISO/SA1)
unnamed: R9.2, U1.25 (REXT)
unnamed: R17.1, R19.2, U1.3 (SSN/SA0)
unnamed: R11.2, U1.18 (XDRVN)
unnamed: R10.2, U1.15 (XDRVP)
unnamed: L7.2, R11.1, U1.17 (XINN)
unnamed: L7.1, R10.1, U1.16 (XINP)
unnamed: R13.2, U1.13 (YDRVN)
unnamed: R12.2, U1.10 (YDRVP)
unnamed: L8.2, R13.1, U1.12 (YINN)
unnamed: L8.1, R12.1, U1.11 (YINP)
unnamed: R15.2, U1.9 (ZDRVN)
unnamed: R14.2, U1.6 (ZDRVP)
unnamed: L9.2, R15.1, U1.8 (ZINN)
unnamed: L9.1, R14.1, U1.7 (ZINP)
unnamed: R20.2, R21.1, U2.28 (MISO/SA1)
unnamed: R8.2, U2.25 (REXT)
unnamed: R22.2, R23.1, U2.3 (SSN/SA0)
unnamed: R3.2, U2.18 (XDRVN)
unnamed: R1.2, U2.15 (XDRVP)
unnamed: L4.2, R3.1, U2.17 (XINN)
unnamed: L4.1, R1.1, U2.16 (XINP)
unnamed: R5.2, U2.13 (YDRVN)
unnamed: R4.2, U2.10 (YDRVP)
unnamed: L3.2, R5.1, U2.12 (YINN)
unnamed: L3.1, R4.1, U2.11 (YINP)
unnamed: R7.2, U2.9 (ZDRVN)
unnamed: R6.2, U2.6 (ZDRVP)
unnamed: L5.2, R7.1, U2.8 (ZINN)
unnamed: L5.1, R6.1, U2.7 (ZINP)

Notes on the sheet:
PIN 1 INDICATOR HERE
Firmware: "PZ2"
DRVP/DRVN TRACES SHOULD BE EXACT EQUAL LENGTH PER SENSOR COUPLE (Why? this isn't in the datasheets?)
Address bits: 00
+Z+X-Y Corner
U.Fl to U.Fl coax through hole to +Z End Card E.g., Cinch Connectivity 415-0088-100
Front Fiducials
DRVP/DRVN TRACES MUST BE EXACT EQUAL LENGTH PER SENSOR COUPLE
I2C Address: 0x21
All resistors 0603 1% and AEQ unless otherwise noted. All capacitors 0603 10% X5R Wv >= 25V and AEQ or better unless otherwise noted.
3.3V and I2C signals are provide by the Mag card via the SPARE lines on the backplane: MAG-SDA = SPARE1 + SPARE2 MAG-SCL = SPARE3 + SPARE4 MAG-PWR = SPARE5 + SPARE6. These lines are delivered via the 12 pin connector on the +Z end card
Back Fiducials
I2C Address: 0x20
0805
Firmware: "PZ1"
Z axis of RM3100 is "down" (the coils are set for North/East/Down) so for the +Z end cap, the Z sensor on the bottom of the board is actually pointed in the right direction!
+Z-X+Y Corner
Backup S Band patch antenna
MAG-PWR
Address bits: 01

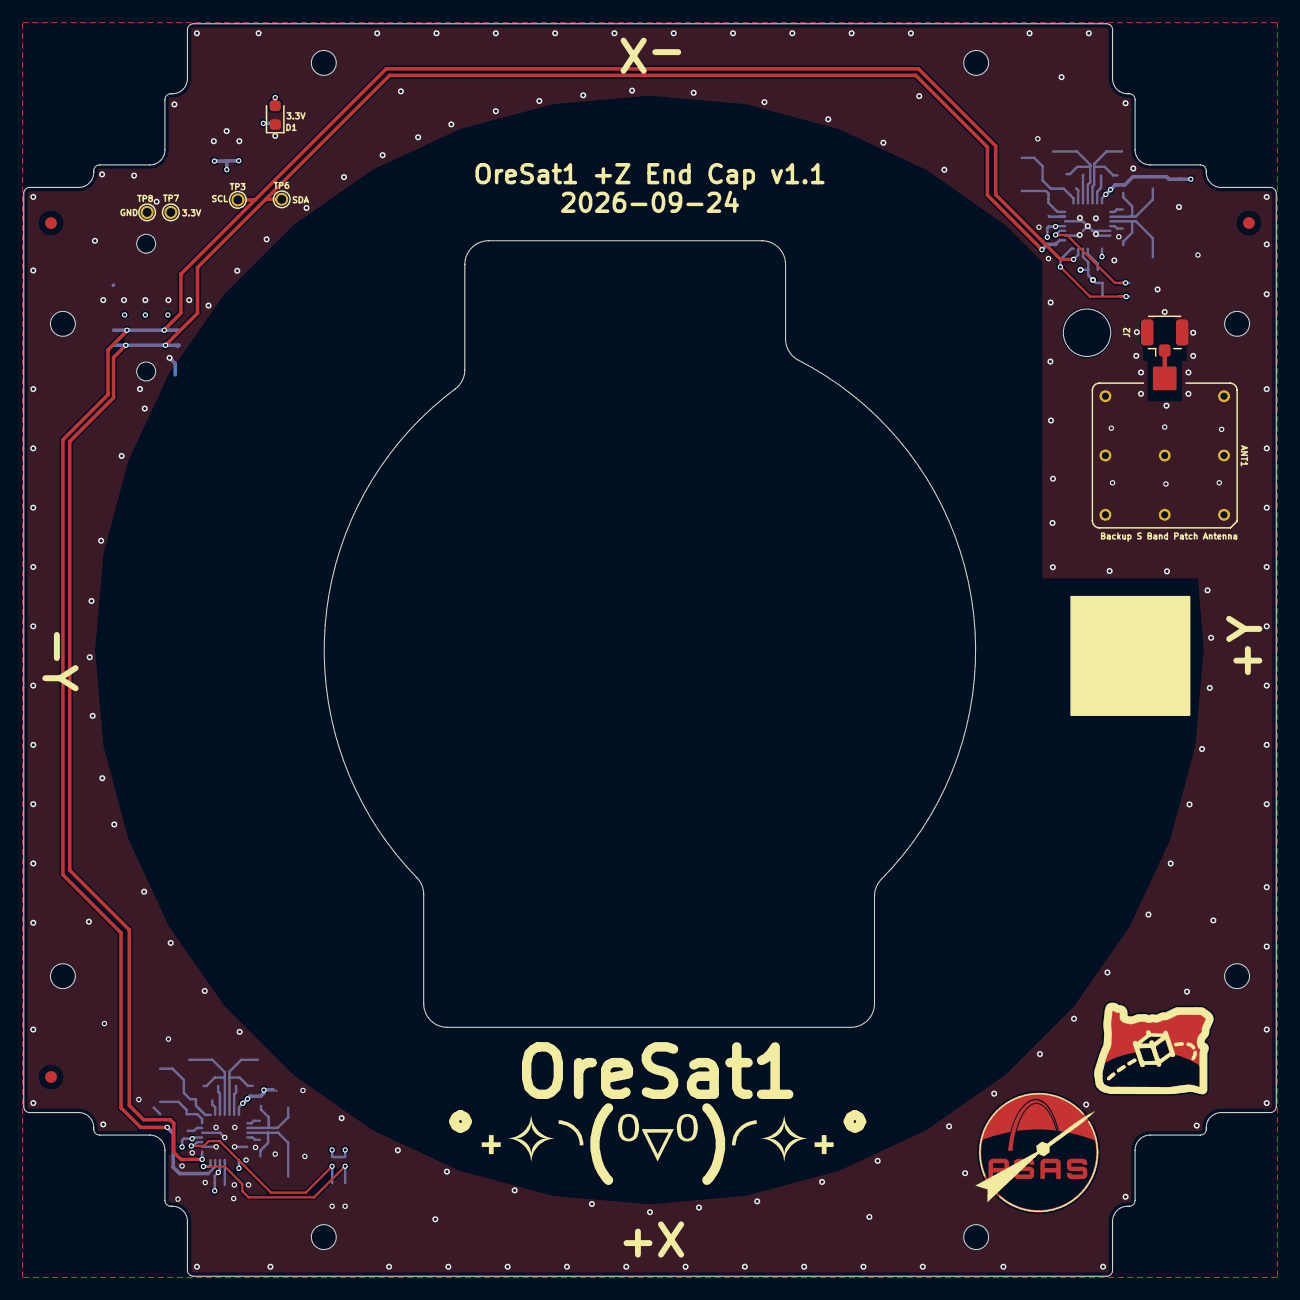
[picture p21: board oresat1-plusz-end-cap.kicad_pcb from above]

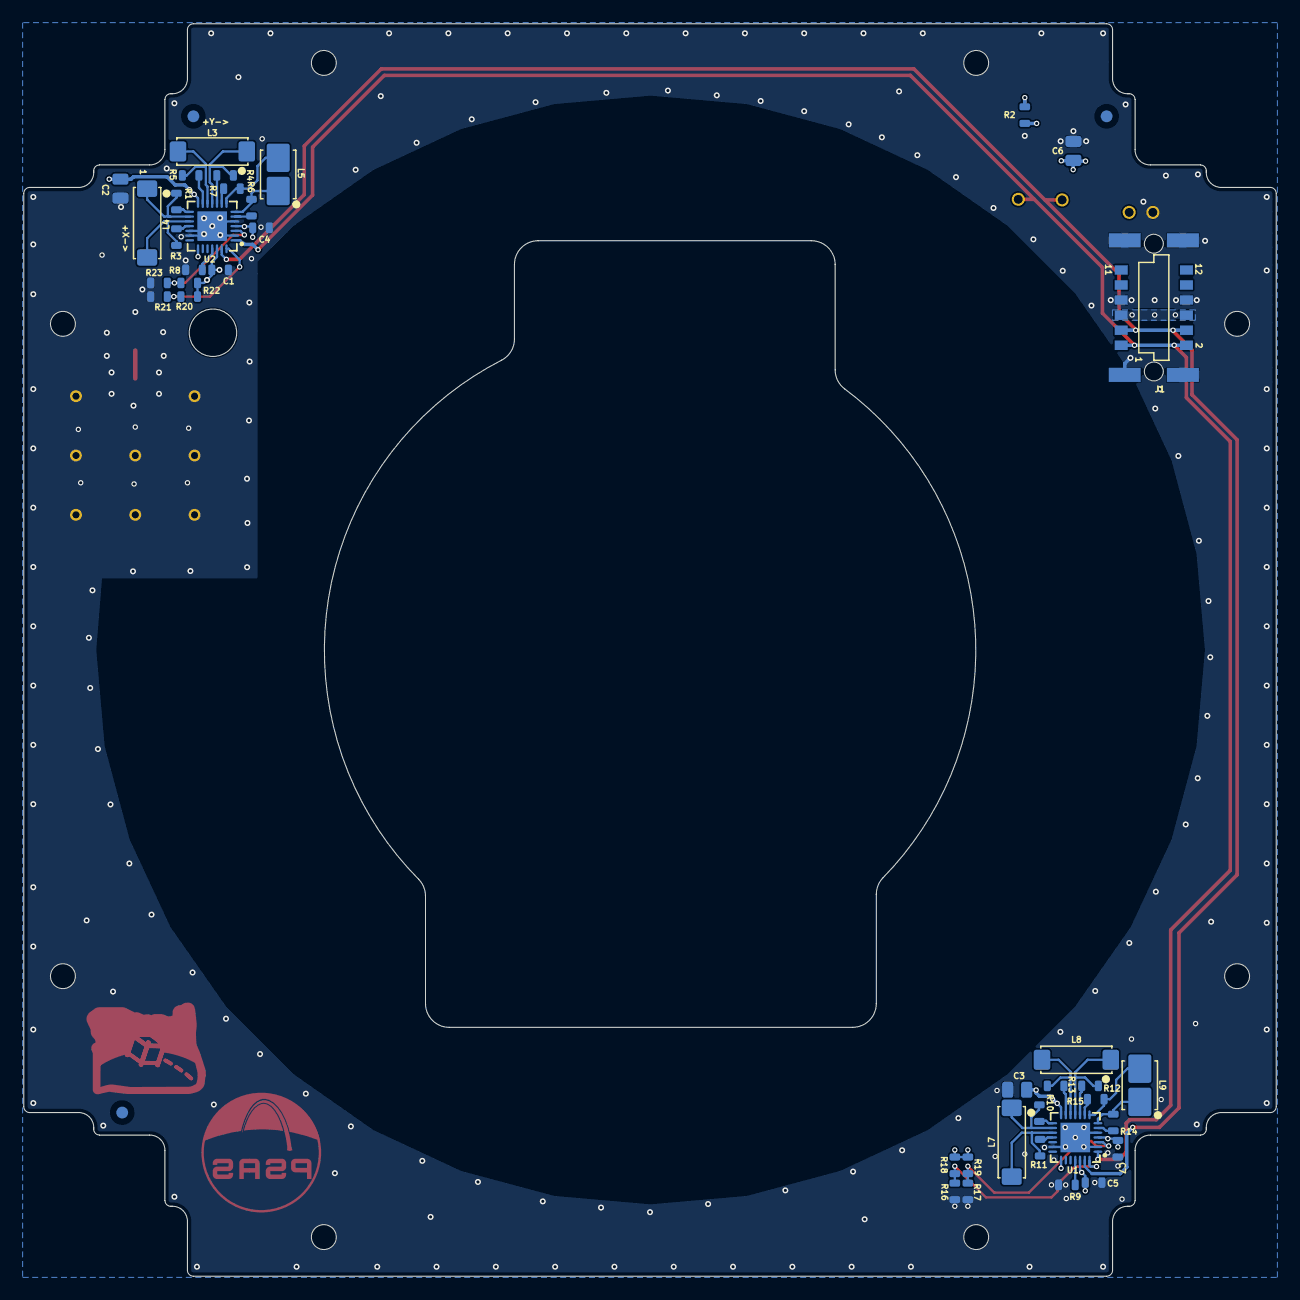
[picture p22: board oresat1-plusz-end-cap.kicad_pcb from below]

Board: 4 copper layers, 105.6 x 105.6 mm, 61 parts (42 on the bottom side), 36 nets.

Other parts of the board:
@HOLE4, @HOLE4#2, @HOLE4#3, @HOLE4#4, @HOLE4#5, @HOLE4#6, @HOLE4#7, @HOLE4#8: MountingHole_2.1mm
LOGO1: PSAS_LOGO_10X10

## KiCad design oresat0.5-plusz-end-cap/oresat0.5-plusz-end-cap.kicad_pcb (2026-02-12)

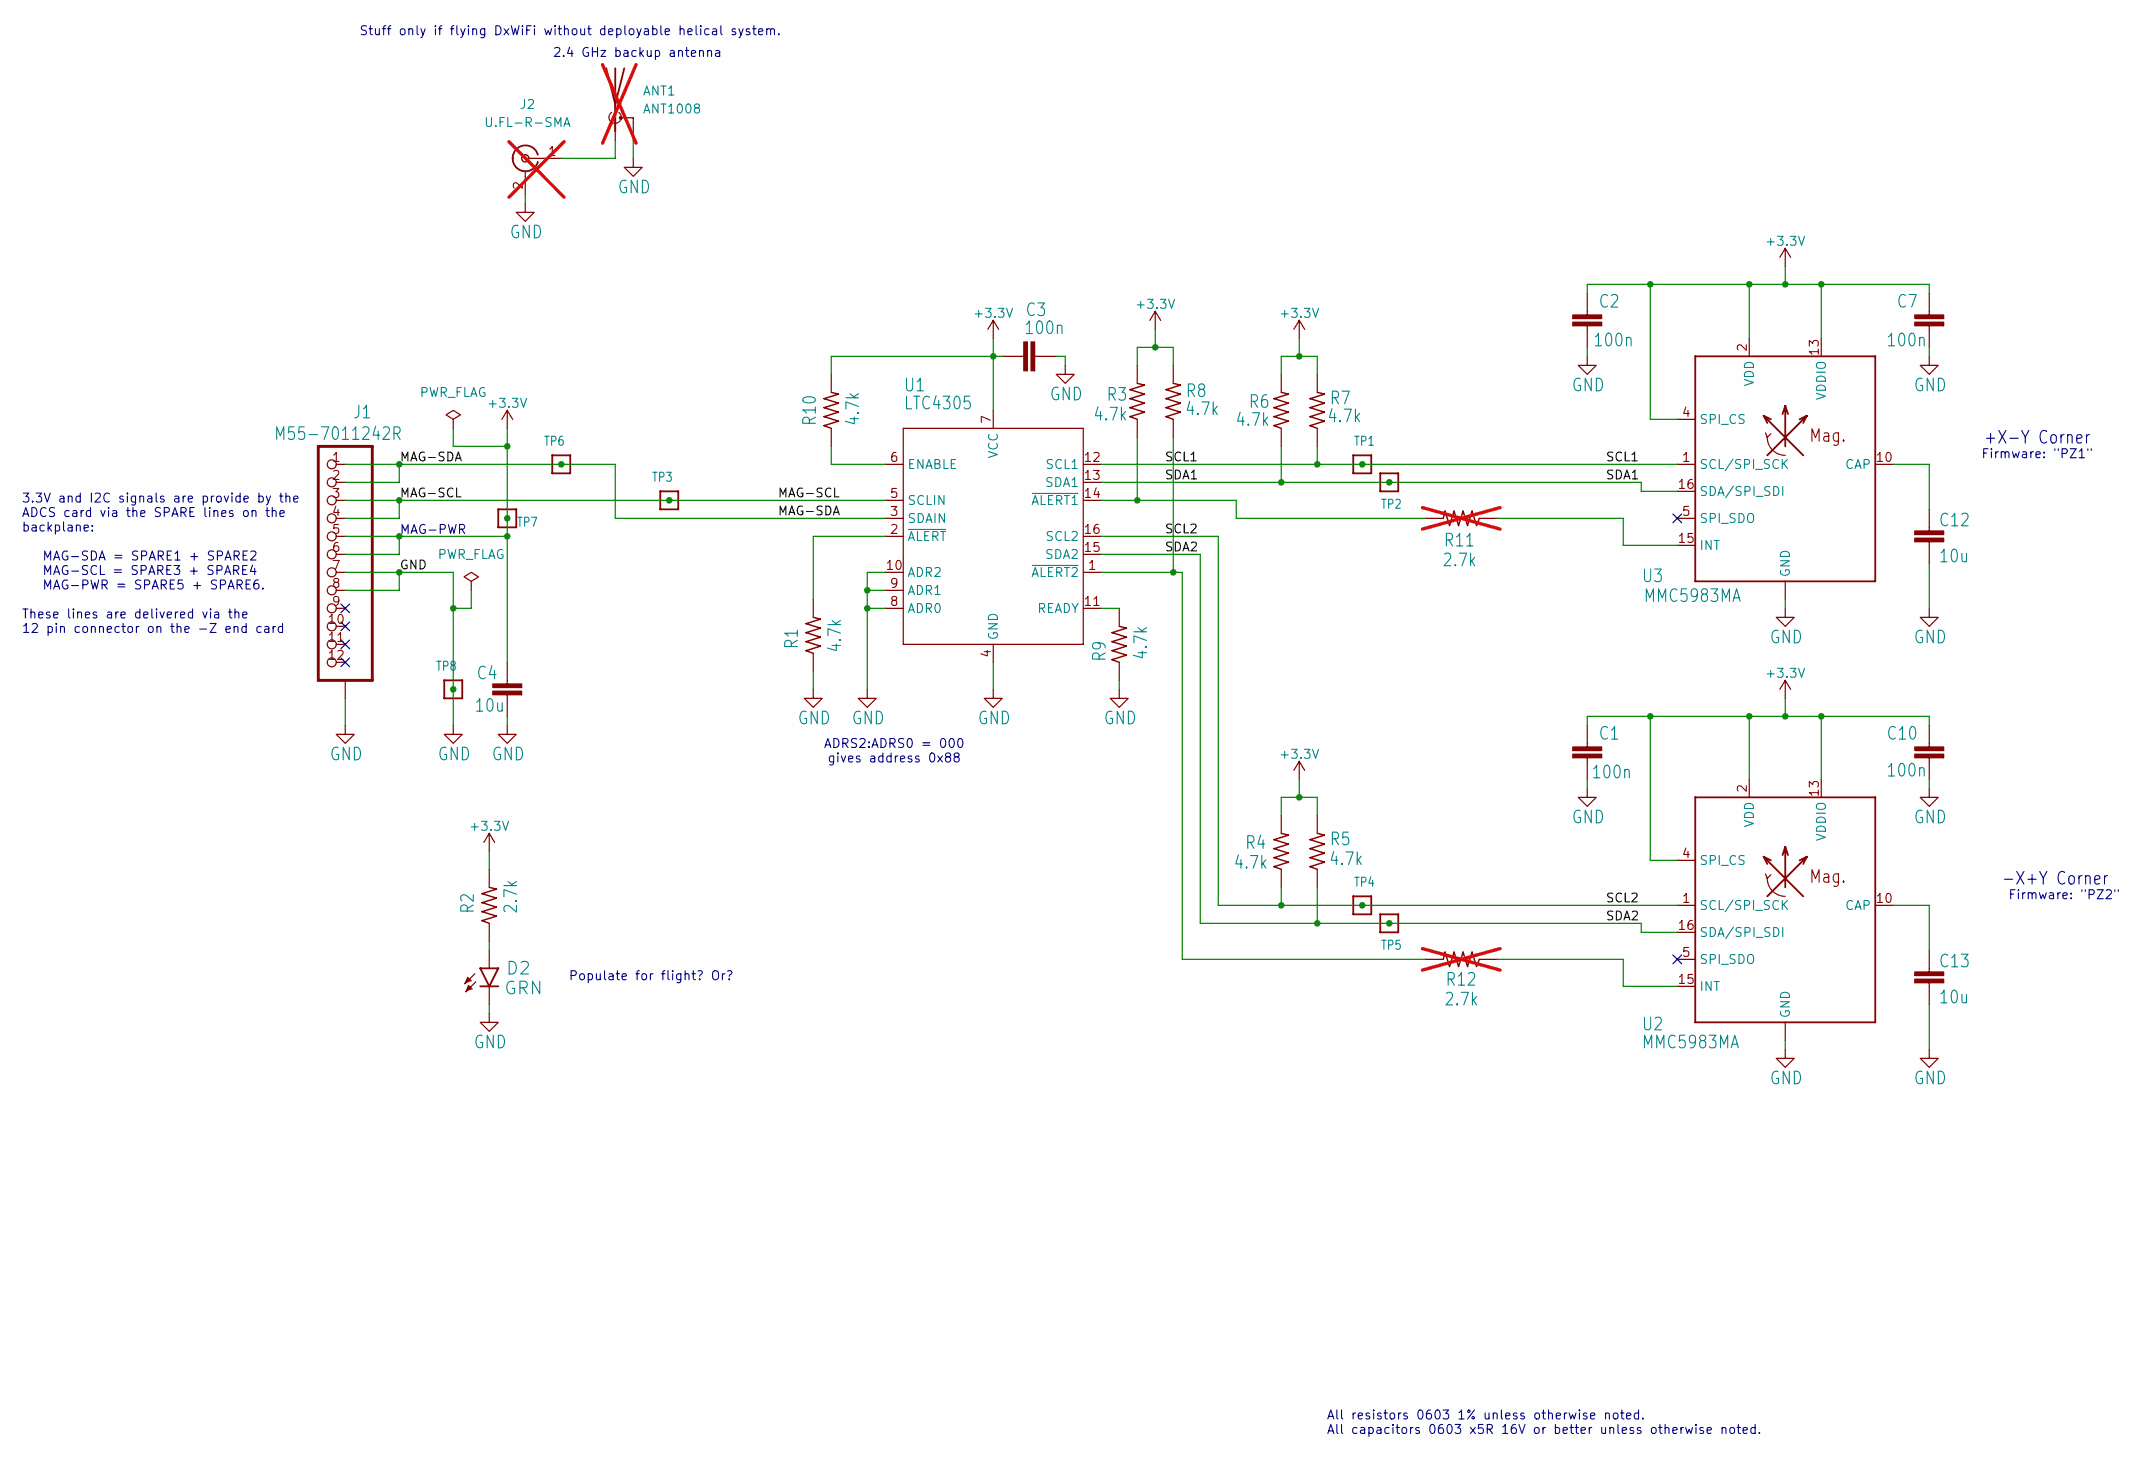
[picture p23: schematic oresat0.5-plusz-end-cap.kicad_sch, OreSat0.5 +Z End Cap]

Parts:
ANT1: ANT1008; RFMi-ANT1008-S-Band-Patch; MPN ANT1008; not fitted
C1, C2, C3, C7, C10: 100n; .0603-B-NOSILK; MPN TMK107BJ104KAHT
C4, C12, C13: 10u; .0603-B-NOSILK; MPN GRT188R61C106KE13D
D2: GRN; LED-0603; MPN 150060GS75000
J1: M55-7011242R; HARWIN-M55-70X1242R; MPN M55-7011242R
J2: U.FL-R-SMA; U.FL_Hirose_U.FL-R-SMT-1_Vertical; MPN U.FL-R-SMT-1(10); not fitted
R1, R3, R4, R5, R6, R7, R8, R9, R10: 4.7k; .0603-B-NOSILK; MPN RMCF0603FT4K70
R2: 2.7k; .0603-B-NOSILK; MPN RMCF0603FT2K70
R11, R12: 2.7k; .0603-B-NOSILK; MPN RMCF0603FT2K70; not fitted
TP1, TP2, TP3, TP4, TP5, TP6, TP7, TP8: TEST-POINT-LARGE-SQUARE; TestPoint-0.75mm-th; MPN N/A
U1: LTC4305; 16-SSOP; MPN LTC4305IGN#PBF
U2, U3: MMC5983MA; LGA-16(3X3); MPN MMC5883MA

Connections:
+3.3V: C1.1, C2.1, C3.1, C4.1, C7.1, C10.1, J1.5, J1.6, R2.2, R3.2, R4.2, R5.2, R6.2, R7.2, R8.2, R10.2, TP7.1, U1.7 (VCC), U2.2 (VDD), U2.4 (SPI_CS), U2.13 (VDDIO), U3.2 (VDD), U3.4 (SPI_CS), U3.13 (VDDIO)
/MAG-SCL: J1.3, J1.4, TP3.1, U1.5 (SCLIN)
/MAG-SDA: J1.1, J1.2, TP6.1, U1.3 (SDAIN)
/SCL1: R7.1, TP1.1, U1.12 (SCL1), U3.1 (SCL/SPI_SCK)
/SCL2: R4.1, TP4.1, U1.16 (SCL2), U2.1 (SCL/SPI_SCK)
/SDA1: R6.1, TP2.1, U1.13 (SDA1), U3.16 (SDA/SPI_SDI)
/SDA2: R5.1, TP5.1, U1.15 (SDA2), U2.16 (SDA/SPI_SDI)
GND: ANT1.2 (Shield), C1.2, C2.2, C3.2, C4.2, C7.2, C10.2, C12.2, C13.2, D2.C, J1.7, J1.8, J1.P$1 (SHIELDS), J1.P$2 (SHIELDS), J1.P$3 (SHIELDS), J1.P$4 (SHIELDS), J2.2 (Ext), R1.1, R9.1, TP8.1, U1.4 (GND), U1.8 (ADR0), U1.9 (ADR1), U1.10 (ADR2), U2.9 (GND), U2.11 (GND), U3.9 (GND), U3.11 (GND)
unnamed: ANT1.1 (A), J2.1 (In)
unnamed: D2.A, R2.1
unnamed: R10.1, U1.6 (ENABLE)
unnamed: R9.2, U1.11 (READY)
unnamed: R3.1, R11.2, U1.14 (~ALERT1)
unnamed: R8.1, R12.2, U1.1 (~ALERT2)
unnamed: R1.2, U1.2 (~ALERT)
unnamed: C13.1, U2.10 (CAP)
unnamed: R12.1, U2.15 (INT)
unnamed: C12.1, U3.10 (CAP)
unnamed: R11.1, U3.15 (INT)

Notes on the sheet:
-X+Y Corner
MAG-PWR
All resistors 0603 1% unless otherwise noted. All capacitors 0603 x5R 16V or better unless otherwise noted.
Stuff only if flying DxWiFi without deployable helical system.
Populate for flight? Or?
Firmware: "PZ2"
+X-Y Corner
ADRS2:ADRS0 = 000 gives address 0x88
Firmware: "PZ1"
3.3V and I2C signals are provide by the ADCS card via the SPARE lines on the backplane: MAG-SDA = SPARE1 + SPARE2 MAG-SCL = SPARE3 + SPARE4 MAG-PWR = SPARE5 + SPARE6. These lines are delivered via the 12 pin connector on the -Z end card
2.4 GHz backup antenna

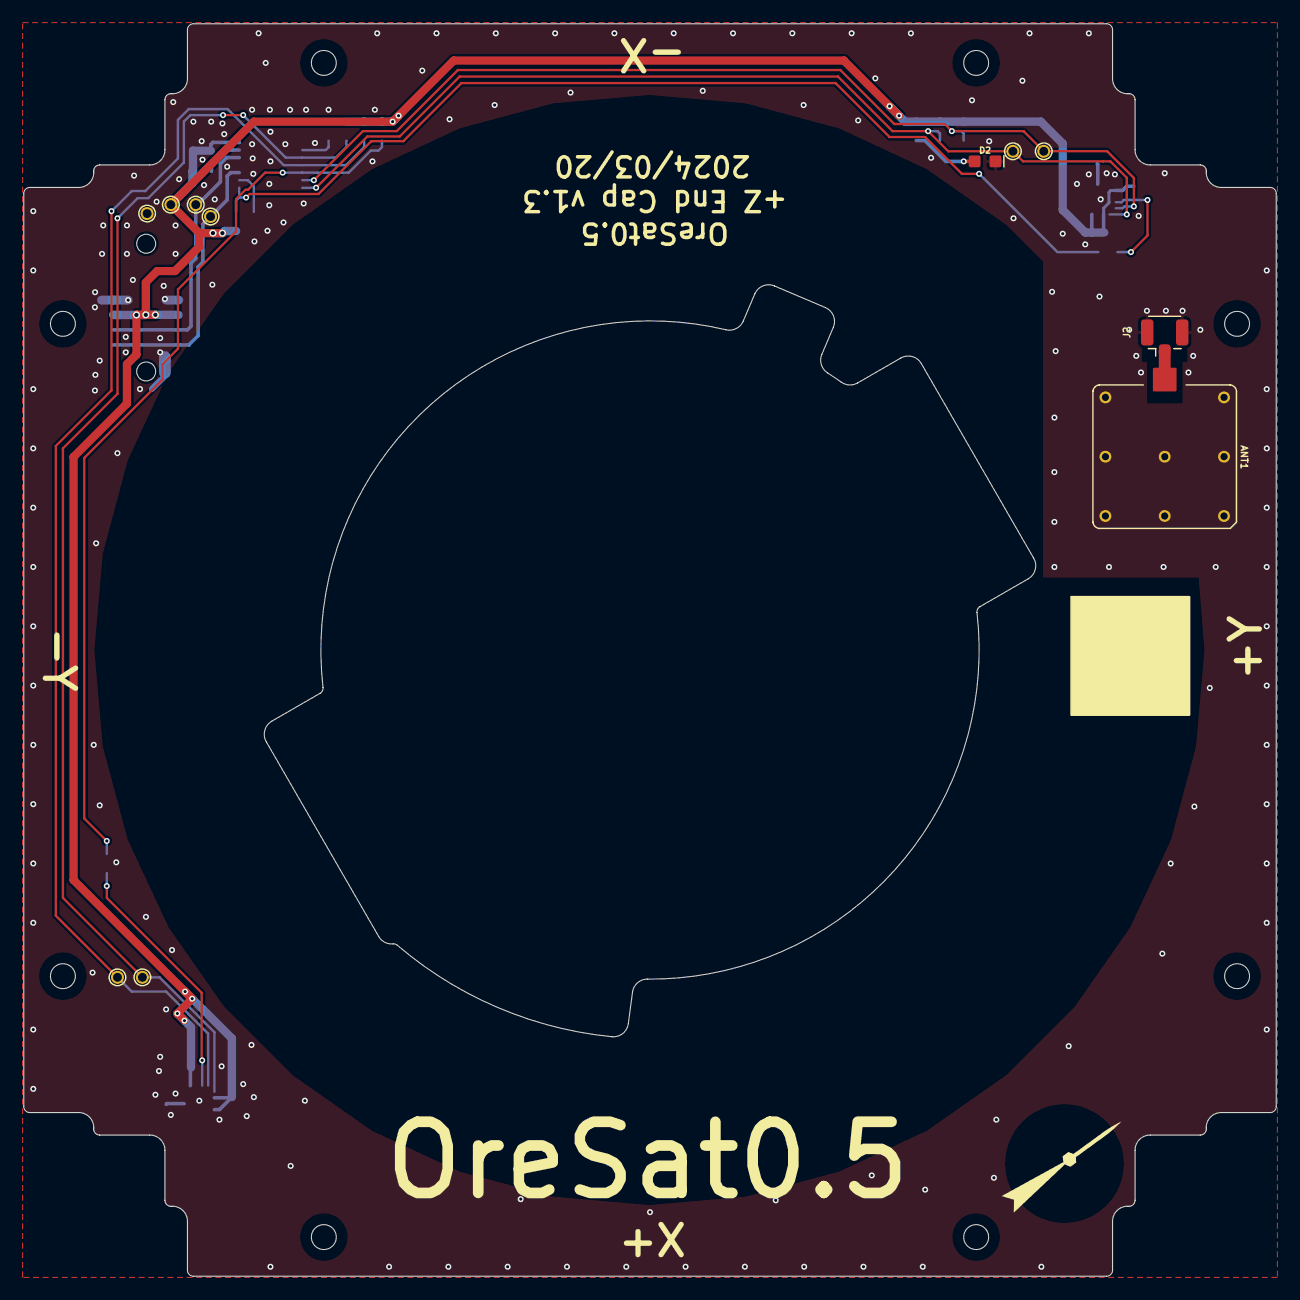
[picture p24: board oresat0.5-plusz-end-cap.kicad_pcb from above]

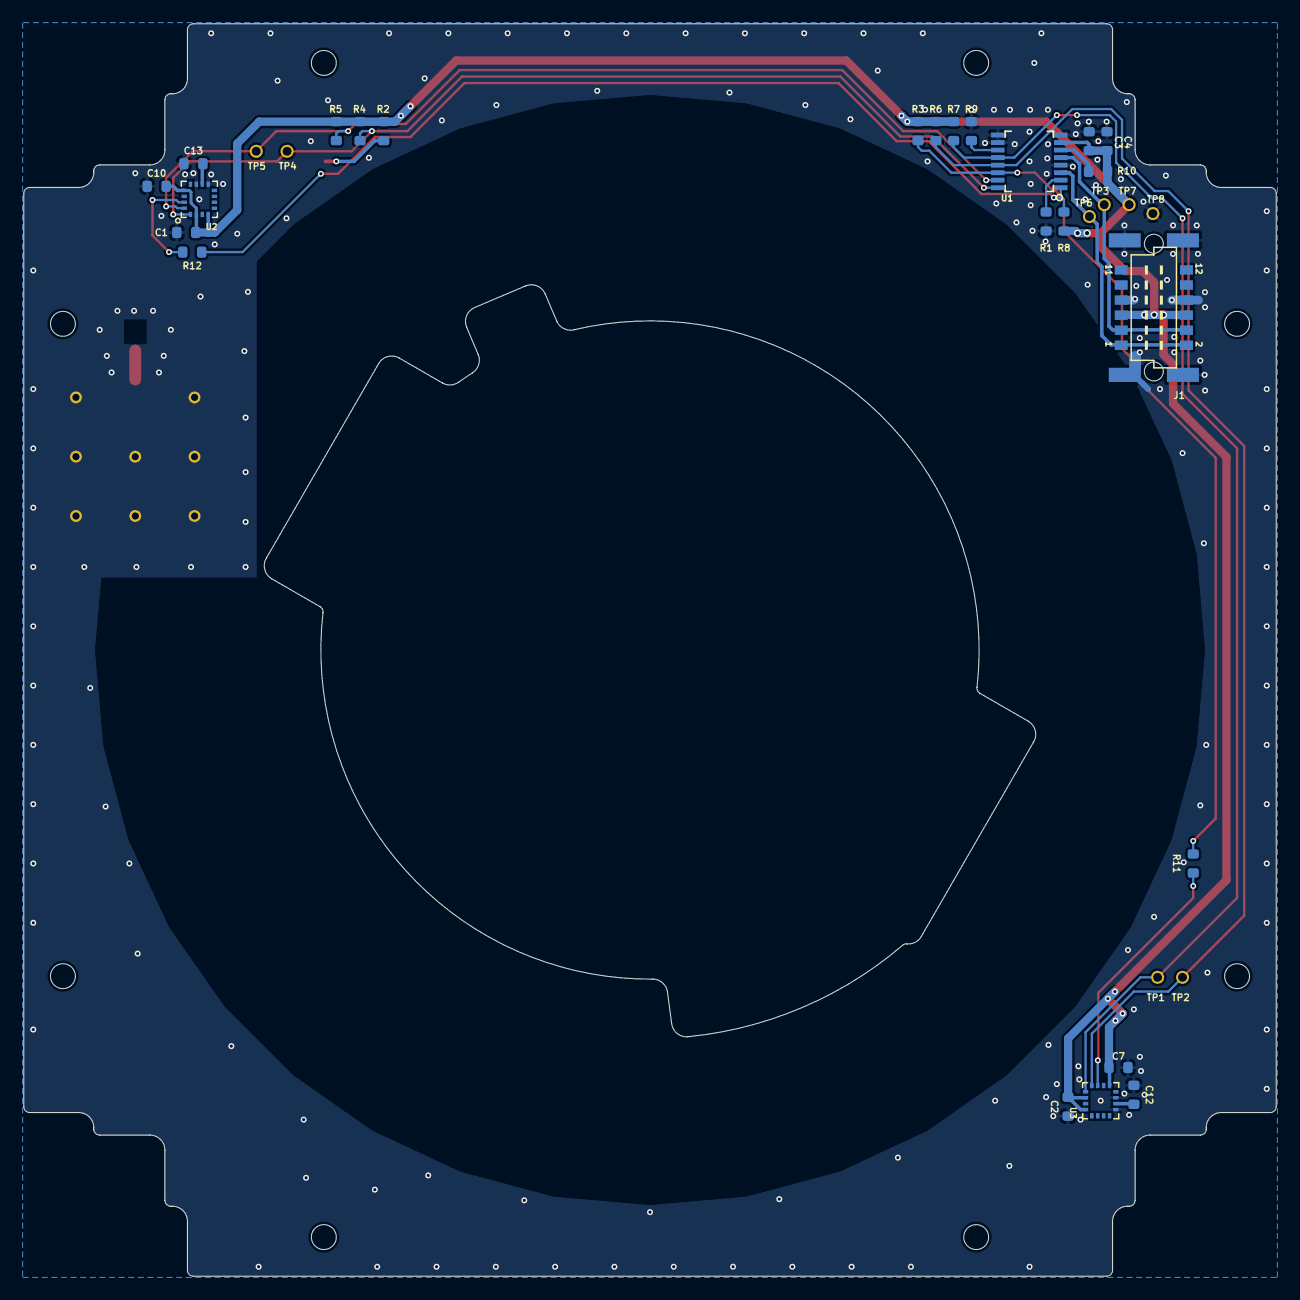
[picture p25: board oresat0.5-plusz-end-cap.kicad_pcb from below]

Board: 2 copper layers, 105.6 x 105.6 mm, 44 parts (24 on the bottom side), 19 nets.

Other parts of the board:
@HOLE4, @HOLE4#2, @HOLE4#3, @HOLE4#4, @HOLE4#5, @HOLE4#6, @HOLE4#7, @HOLE4#8: MountingHole_2.1mm
LOGO1: PSAS_LOGO_10X10

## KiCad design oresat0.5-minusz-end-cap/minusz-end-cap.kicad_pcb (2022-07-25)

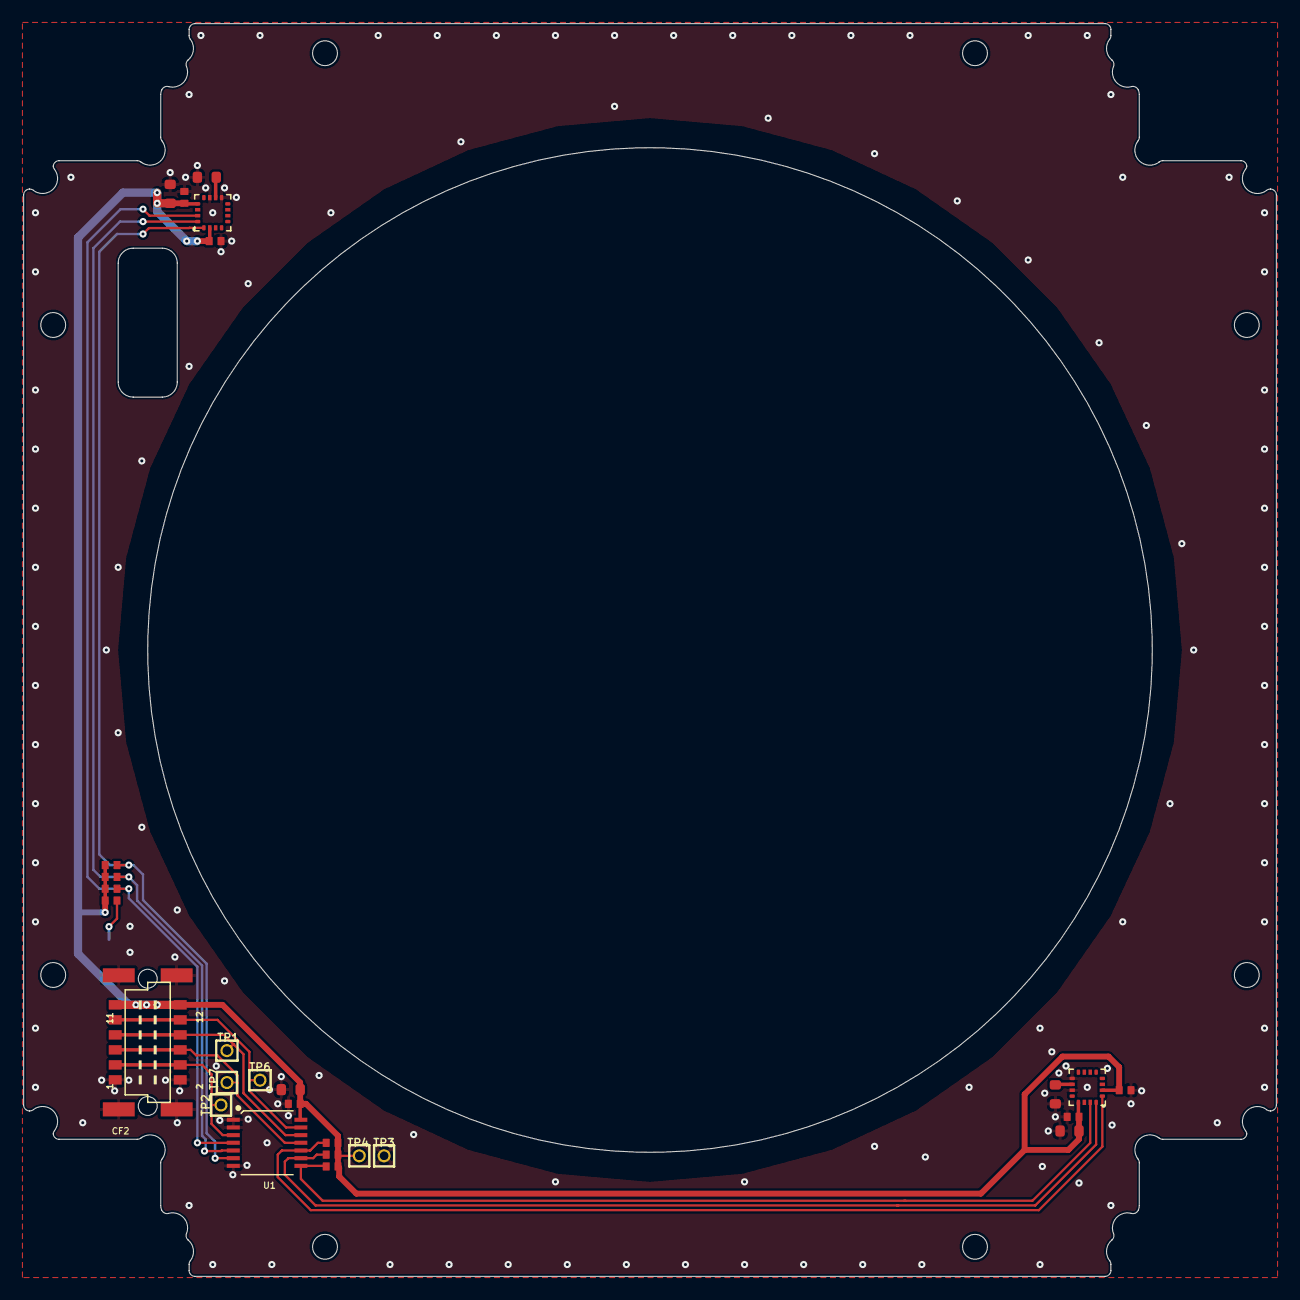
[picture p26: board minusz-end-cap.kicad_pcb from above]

Board: 2 copper layers, 106.0 x 106.0 mm, 36 parts (1 on the bottom side), 15 nets.

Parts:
@HOLE0, @HOLE1, @HOLE2, @HOLE3, @HOLE4, @HOLE5, @HOLE6, @HOLE7: (no value)
C1, C2, C3, C7, C10: 100n; .0402-B-NOSILK
C4, C12, C13: 10u; .0603-B-NOSILK
C15, C19: 4.7u; .0603-B-NOSILK
CF2: J-HARWIN-M55-70X1242R; HARWIN-M55-70X1242R
D2: GREEN; LED-0603
R1, R3, R4, R5, R6, R7: 4.7k; .0402-B-NOSILK
R2: 2.7k; .0402-B-NOSILK
TP1, TP2, TP3, TP4, TP6, TP7: TEST-POINT; 2MM-TEST-POINT
U1: TCA9543A-PW; TSSOP14-0.65-5.4X4.4MM
U3, U4: HMC5883L; QLGA-16(3X3)

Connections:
3.3V: C1.1, C2.1, C3.1, C4.1, C7.1, C10.1, C15.1, C19.1, CF2.11, CF2.12, R1.2, R2.2, R3.2, R4.2, R5.2, R6.2, R7.2, TP4.1, U1.14, U3.2, U3.13, U4.2, U4.13
GND: C1.2, C2.2, C3.2, C4.2, C7.2, C10.2, C12.2, C13.2, C15.2, C19.2, CF2.1, CF2.2, CF2.P$1, CF2.P$2, CF2.P$3, CF2.P$4, D2.C, TP3.1, U1.1, U1.2, U1.7, U3.9, U3.11, U4.9, U4.11
I2C-SCL: CF2.7, CF2.8, TP1.1, U1.12
I2C-SDA: CF2.9, CF2.10, TP6.1, U1.13
I2C-~INT: CF2.5, CF2.6, TP7.1, U1.11
unnamed: C12.1, U3.10
unnamed: C13.1, U4.10
unnamed: D2.A, R2.1
SC1: R7.1, U1.10, U3.1
SCL0: R4.1, U1.6, U4.1
SD1: R6.1, U1.9, U3.16
SDA0: R5.1, U1.5, U4.16
~I2C-RESET: CF2.3, CF2.4, TP2.1, U1.3
~INT0: R1.1, U1.4, U4.15
~INT1: R3.1, U1.8, U3.15

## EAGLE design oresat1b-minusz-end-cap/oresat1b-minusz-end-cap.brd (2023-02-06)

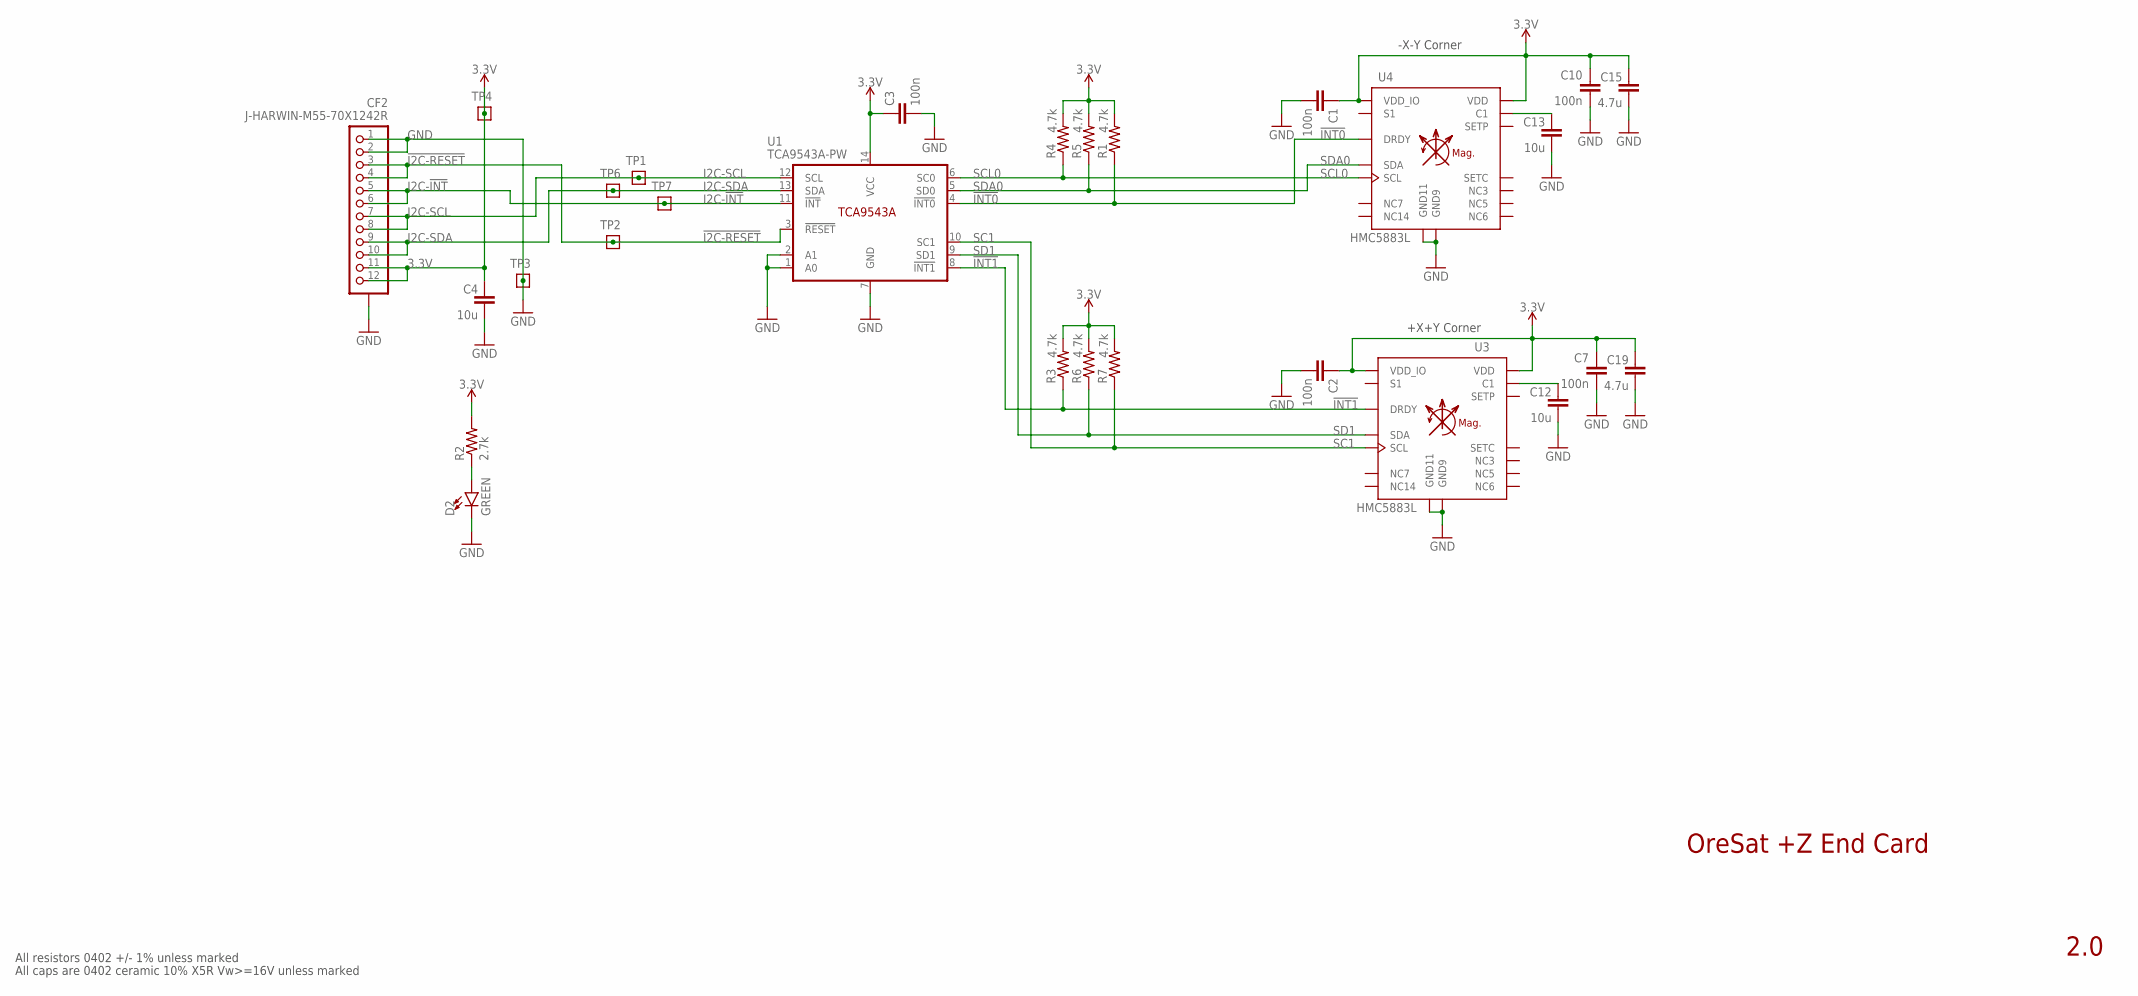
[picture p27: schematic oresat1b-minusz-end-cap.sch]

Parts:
C1, C2, C3, C7, C10: 100n; .0402-B-NOSILK; MPN CL05B104KO5NNNC
C4, C12, C13: 10u; .0603-B-NOSILK; MPN CL05B104KO5NNNC
C15, C19: 4.7u; .0603-B-NOSILK; MPN CL05B104KO5NNNC
CF2: J-HARWIN-M55-70X1242R; HARWIN-M55-70X1242R
D2: GREEN; LED-0603
R1, R3, R4, R5, R6, R7: 4.7k; .0402-B-NOSILK; MPN RC1005F6653CS
R2: 2.7k; .0402-B-NOSILK; MPN RC1005F6653CS
TP1, TP2, TP3, TP4, TP6, TP7: TEST-POINT; 2MM-TEST-POINT
U1: TCA9543A-PW; TSSOP14-0.65-5.4X4.4MM
U3, U4: HMC5883L; QLGA-16(3X3)

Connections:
3.3V: C1.1, C2.1, C3.1, C4.1, C7.1, C10.1, C15.1, C19.1, CF2.11, CF2.12, R1.2, R2.2, R3.2, R4.2, R5.2, R6.2, R7.2, TP4.1, U1.14 (VCC), U3.2 (VDD), U3.13 (VDD_IO), U4.2 (VDD), U4.13 (VDD_IO)
!I2C-RESET: CF2.3, CF2.4, TP2.1, U1.3 (!RESET)
!INT0: R1.1, U1.4 (!INT0), U4.15 (DRDY)
!INT1: R3.1, U1.8 (!INT1), U3.15 (DRDY)
GND: C1.2, C2.2, C3.2, C4.2, C7.2, C10.2, C12.2, C13.2, C15.2, C19.2, CF2.1, CF2.2, CF2.P$1 (SHIELDS), CF2.P$2 (SHIELDS), CF2.P$3 (SHIELDS), CF2.P$4 (SHIELDS), D2.C, TP3.1, U1.1 (A0), U1.2 (A1), U1.7 (GND), U3.9 (GND9), U3.11 (GND11), U4.9 (GND9), U4.11 (GND11)
I2C-!INT: CF2.5, CF2.6, TP7.1, U1.11 (!INT)
I2C-SCL: CF2.7, CF2.8, TP1.1, U1.12 (SCL)
I2C-SDA: CF2.9, CF2.10, TP6.1, U1.13 (SDA)
unnamed: C12.1, U3.10 (C1)
unnamed: C13.1, U4.10 (C1)
unnamed: D2.A, R2.1
SC1: R7.1, U1.10 (SC1), U3.1 (SCL)
SCL0: R4.1, U1.6 (SC0), U4.1 (SCL)
SD1: R6.1, U1.9 (SD1), U3.16 (SDA)
SDA0: R5.1, U1.5 (SD0), U4.16 (SDA)

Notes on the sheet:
OreSat +Z End Card
2.0
All resistors 0402 +/- 1% unless marked
All caps are 0402 ceramic 10% X5R Vw>=16V unless marked
-X-Y Corner
+X+Y Corner

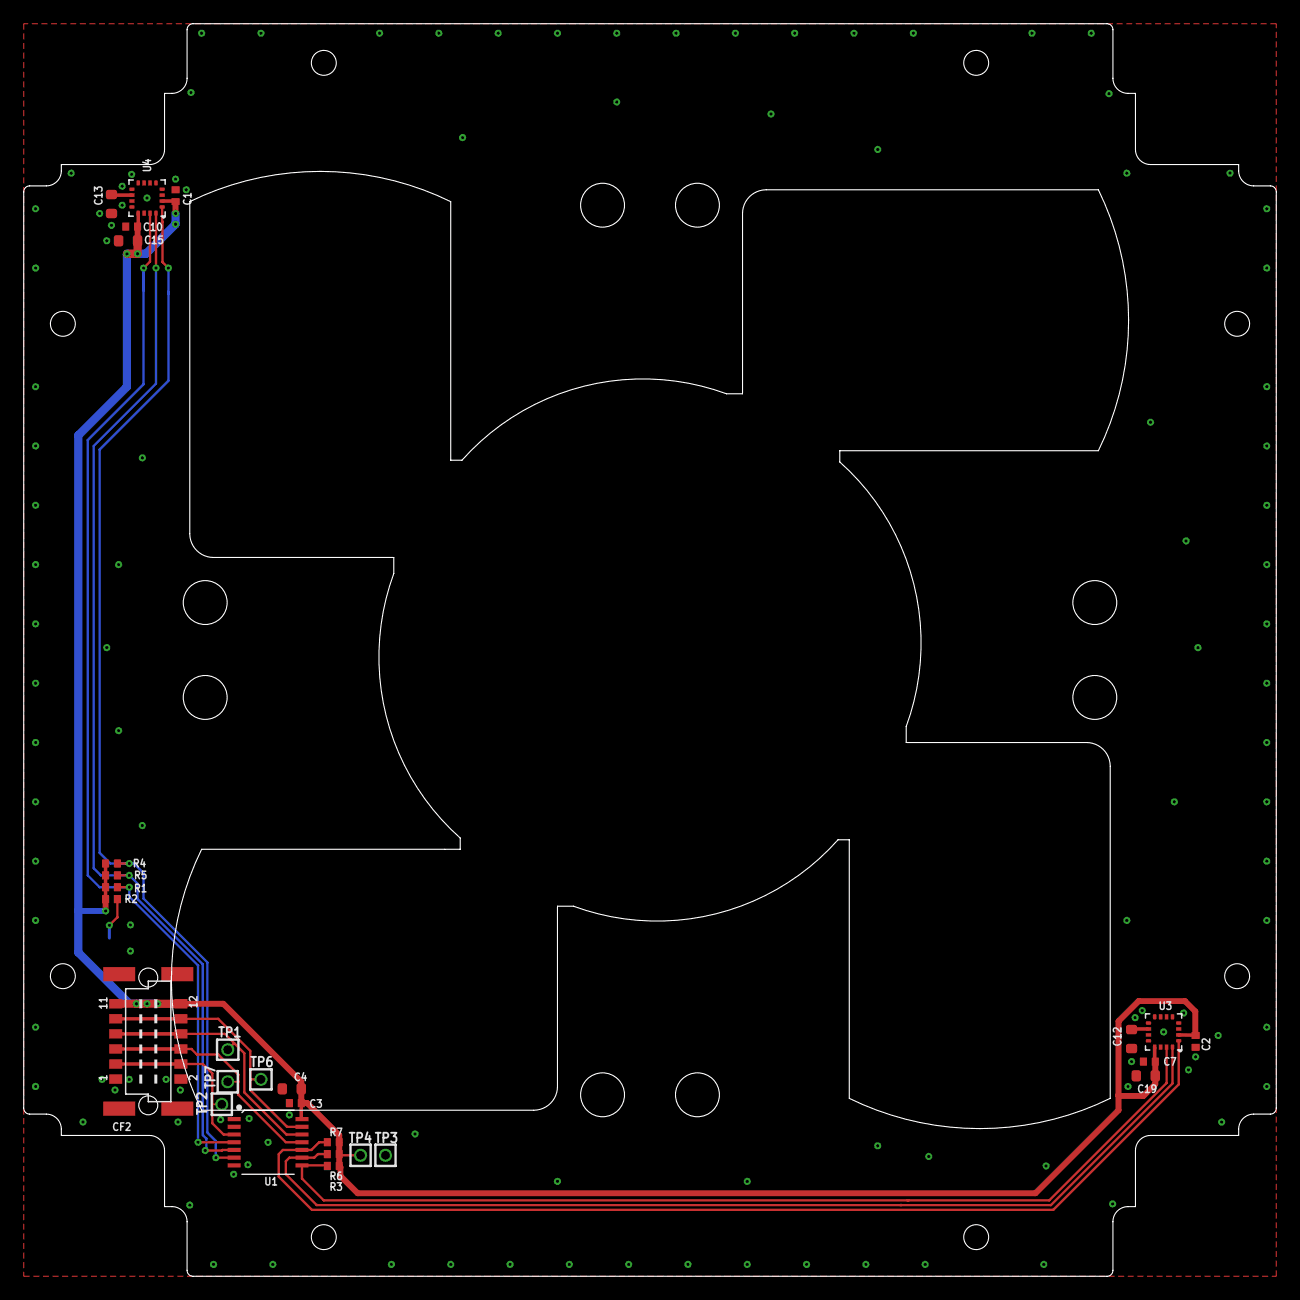
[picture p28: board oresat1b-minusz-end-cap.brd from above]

Board: 2 copper layers, 105.6 x 105.6 mm, 28 parts (1 on the bottom side), 15 nets.

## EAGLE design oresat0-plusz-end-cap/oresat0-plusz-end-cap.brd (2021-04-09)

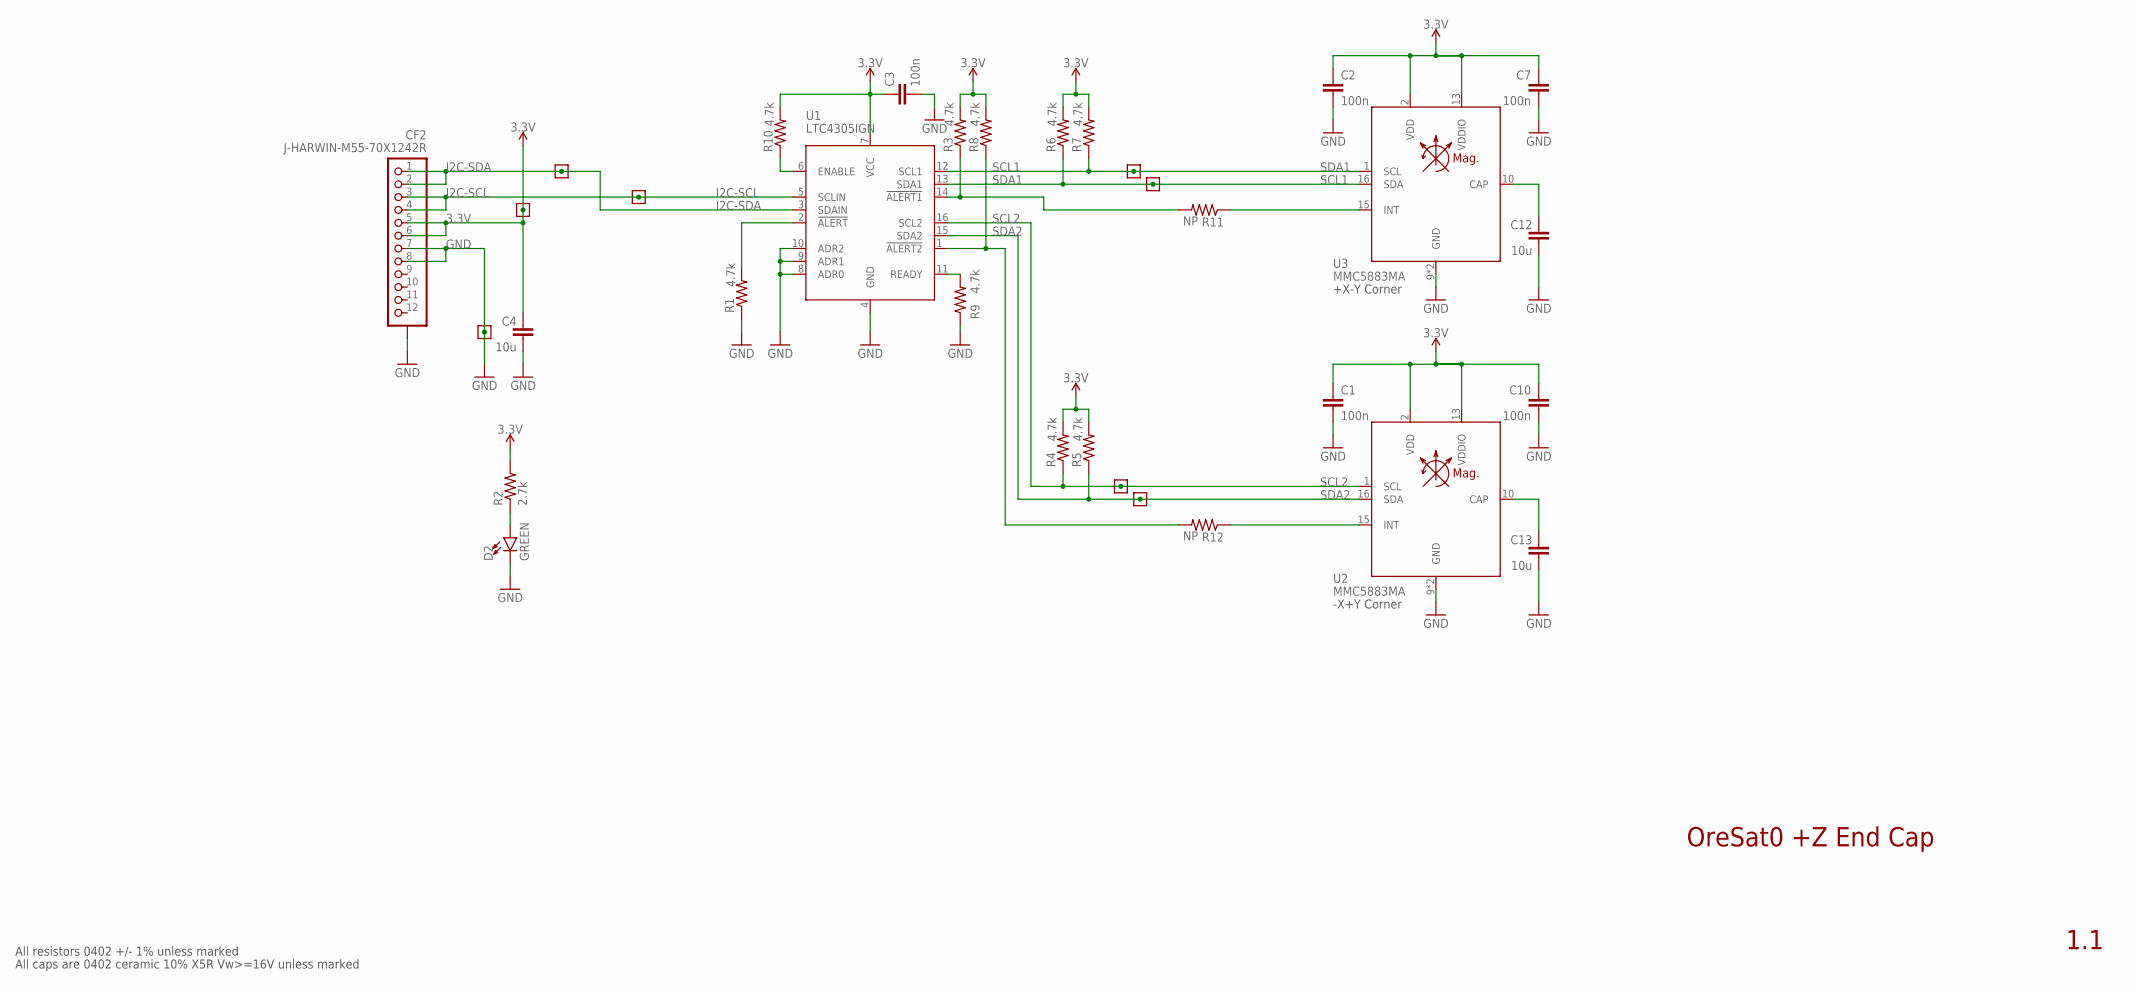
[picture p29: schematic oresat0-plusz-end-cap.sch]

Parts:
C1, C2, C3, C7, C10: 100n; .0603-B-NOSILK; MPN CL10B104KB8NNNL
C4, C12, C13: 10u; .0603-B-NOSILK; MPN GRM188D71A106KA73D
CF2: J-HARWIN-M55-70X1242R; HARWIN-M55-70X1242R; MPN M55-7011242R
D2: GREEN; LED-0603; MPN SML-E12M8WT86
R1, R3, R4, R5, R6, R7, R8, R9, R10: 4.7k; .0603-B-NOSILK; MPN CRGCQ0603F4K7
R2: 2.7k; .0603-B-NOSILK; MPN CRGCQ0603F2K7
R11, R12: NP; .0603-B-NOSILK
TP1, TP2, TP3, TP4, TP5, TP6, TP7, TP8: TEST-POINT-LARGE-SQUARE; 1X01
U1: LTC4305IGN; 16-SSOP; MPN LTC4305IGN#PBF
U2, U3: MMC5883MA; LGA-16(3X3); MPN MMC5883MA

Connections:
3.3V: C1.1, C2.1, C3.1, C4.1, C7.1, C10.1, CF2.5, CF2.6, R2.2, R3.2, R4.2, R5.2, R6.2, R7.2, R8.2, R10.2, TP7.1, U1.7 (VCC), U2.2 (VDD), U2.13 (VDDIO), U3.2 (VDD), U3.13 (VDDIO)
GND: C1.2, C2.2, C3.2, C4.2, C7.2, C10.2, C12.2, C13.2, CF2.7, CF2.8, CF2.P$1 (SHIELDS), CF2.P$2 (SHIELDS), CF2.P$3 (SHIELDS), CF2.P$4 (SHIELDS), D2.C, R1.1, R9.1, TP8.1, U1.4 (GND), U1.8 (ADR0), U1.9 (ADR1), U1.10 (ADR2), U2.9 (GND), U2.11 (GND), U3.9 (GND), U3.11 (GND)
I2C-SCL: CF2.3, CF2.4, TP3.1, U1.5 (SCLIN)
I2C-SDA: CF2.1, CF2.2, TP6.1, U1.3 (SDAIN)
unnamed: R9.2, U1.11 (READY)
unnamed: C12.1, U3.10 (CAP)
unnamed: R1.2, U1.2 (!ALERT)
unnamed: R3.1, R11.2, U1.14 (!ALERT1)
unnamed: C13.1, U2.10 (CAP)
unnamed: R8.1, R12.2, U1.1 (!ALERT2)
unnamed: R11.1, U3.15 (INT)
unnamed: R10.1, U1.6 (ENABLE)
unnamed: R12.1, U2.15 (INT)
unnamed: D2.A, R2.1
SCL1: R7.1, TP1.1, U1.12 (SCL1), U3.1 (SCL)
SCL2: R4.1, TP4.1, U1.16 (SCL2), U2.1 (SCL)
SDA1: R6.1, TP2.1, U1.13 (SDA1), U3.16 (SDA)
SDA2: R5.1, TP5.1, U1.15 (SDA2), U2.16 (SDA)

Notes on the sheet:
OreSat0 +Z End Cap
1.1
All resistors 0402 +/- 1% unless marked
All caps are 0402 ceramic 10% X5R Vw>=16V unless marked
-X+Y Corner
+X-Y Corner

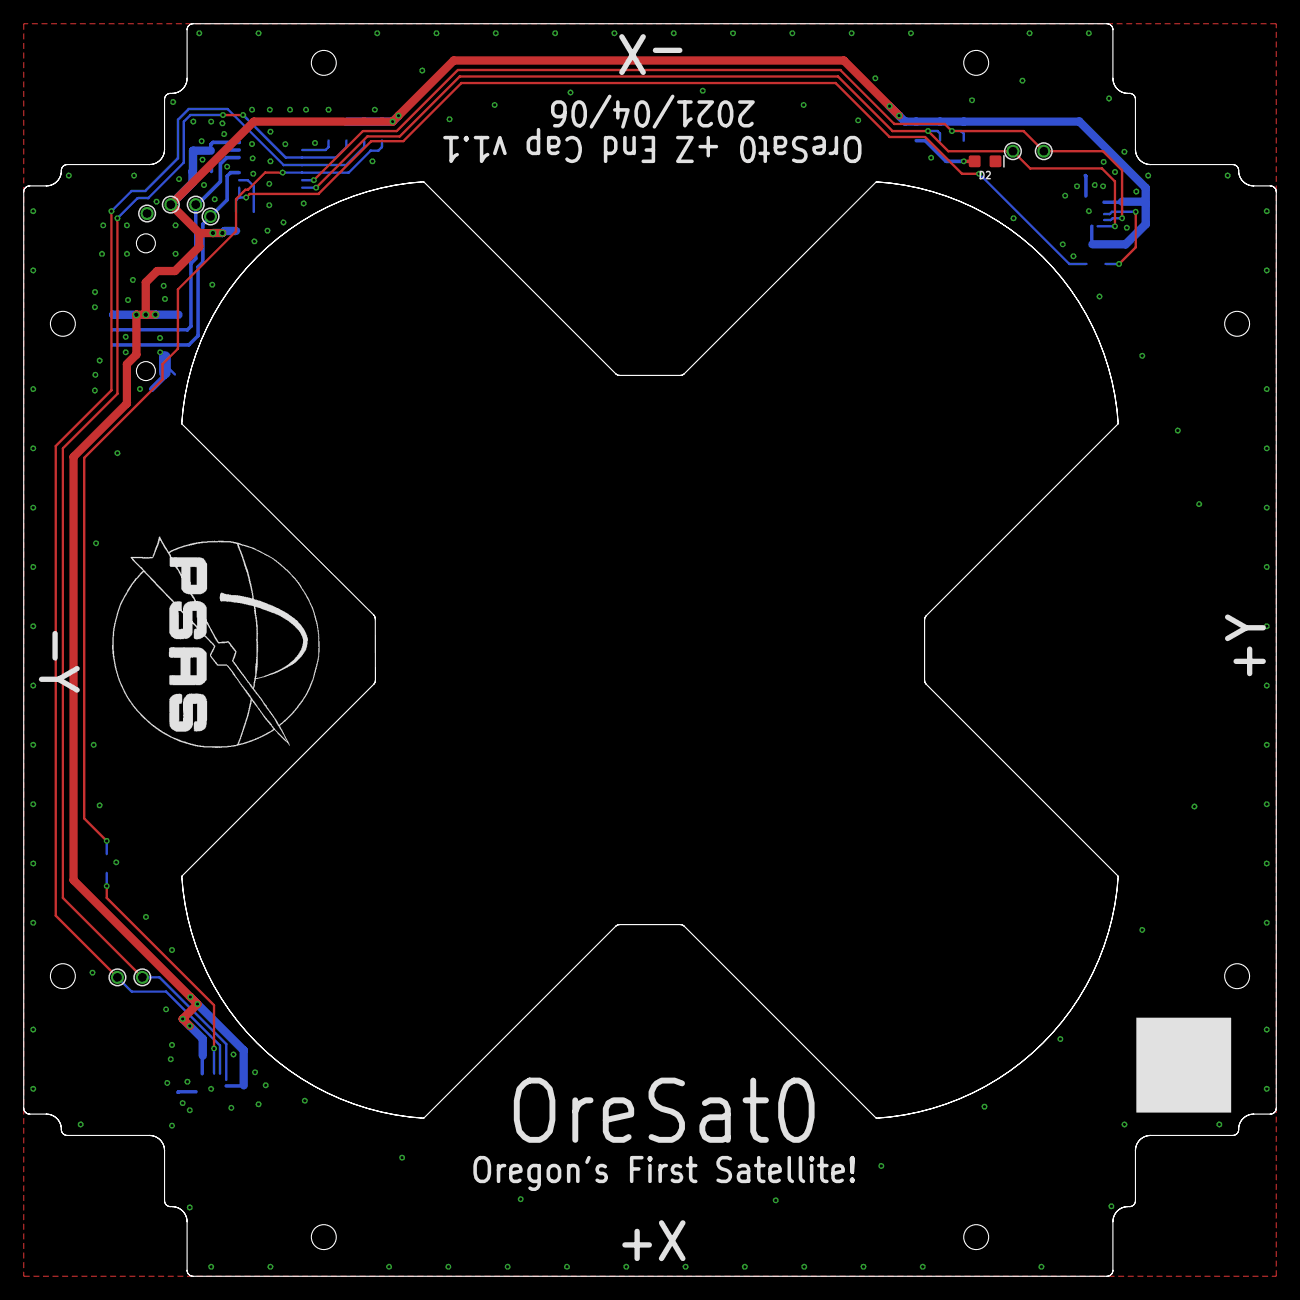
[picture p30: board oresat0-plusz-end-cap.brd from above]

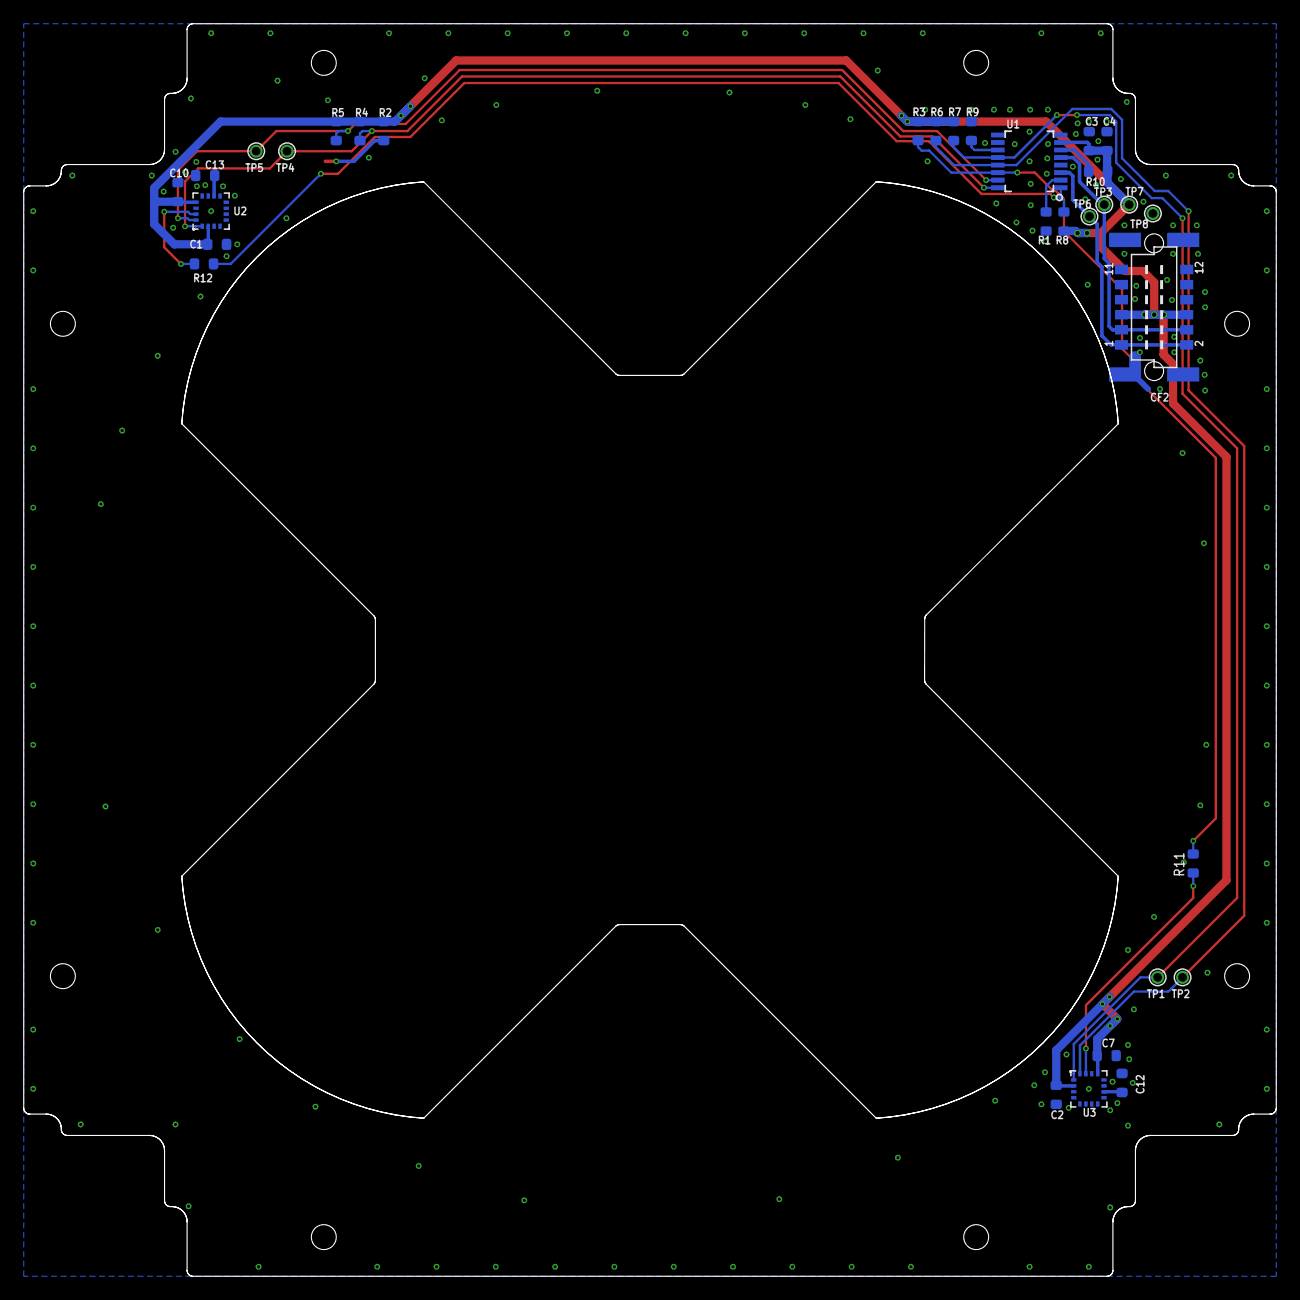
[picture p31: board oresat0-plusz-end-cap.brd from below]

Board: 2 copper layers, 105.6 x 105.6 mm, 33 parts (24 on the bottom side), 18 nets.

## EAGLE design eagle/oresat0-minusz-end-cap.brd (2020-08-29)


Board: 2 copper layers, 105.6 x 105.6 mm, 44 parts (1 on the bottom side), 29 nets.

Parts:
C1, C2, C3, C7, C10: 100n; .0603-B-NOSILK
C4, C12, C13: 10u; .0603-B-NOSILK
D2: GREEN; LED-0603
J1: 6-104178-1
R1, R3, R4, R5, R6, R7, R8, R9, R10: 4.7k; .0603-B-NOSILK
R2: 2.7k; .0603-B-NOSILK
R11, R12: NP; .0603-B-NOSILK
TP1, TP2, TP3, TP4, TP5, TP6, TP7, TP8, TP9, TP10, TP11, TP12, TP13, TP14, TP15, TP16, TP17, TP18, TP19: TEST-POINT-LARGE-SQUARE; 1X01
U1: LTC4305; 16-SSOP
U2, U3: MMC5883MA; LGA-16(3X3)

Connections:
3.3V: C1.1, C2.2, C3.1, C4.1, C7.1, C10.1, J1.15, J1.16, R1.2, R2.2, R3.2, R4.2, R5.2, R6.2, R7.2, R8.2, TP4.1, U1.7, U1.8, U2.2, U2.13, U3.2, U3.13
!SD: J1.1, TP9.1
CAN1_H: J1.4, TP11.1
CAN1_L: J1.3, TP10.1
CAN2_H: J1.9, TP14.1
CAN2_L: J1.8, TP13.1
GND: C1.2, C2.1, C3.2, C4.2, C7.2, C10.2, C12.2, C13.2, D2.C, J1.2, J1.5, J1.6, R9.1, R10.1, TP3.1, U1.4, U1.9, U1.10, U2.9, U2.11, U3.9, U3.11
I2C-SCL: J1.17, J1.18, TP1.1, U1.5
I2C-SDA: J1.19, J1.20, TP6.1, U1.3
unnamed: R8.1, U1.6
unnamed: C12.1, U3.10
unnamed: R1.1, R11.2, U1.14
unnamed: R3.1, R12.2, U1.1
unnamed: C13.1, U2.10
unnamed: R9.2, U1.2
unnamed: R10.2, U1.11
unnamed: R11.1, U3.15
unnamed: R12.1, U2.15
unnamed: D2.A, R2.1
OPD_PWR: J1.10, TP15.1
OPD_SCL: J1.11, TP16.1
OPD_SDA: J1.12, TP17.1
SCL1: R7.1, TP2.1, U1.12, U3.1
SCL2: R4.1, TP7.1, U1.16, U2.1
SDA1: R6.1, TP5.1, U1.13, U3.16
SDA2: R5.1, TP8.1, U1.15, U2.16
SPARE1-TURNSTYLE-DPLY: J1.13, TP18.1
SPARE2: J1.14, TP19.1
VBUS: J1.7, TP12.1

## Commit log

2018-12-03 First try at a end card. Lots of stuff we don't need.
    [oresat-zpos-endcap.brd, oresat-zpos-endcap.sch]
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2018-12-03 Updated version info on the board and readme, and added picture.
    [oresat-zpos-endcap.brd]
2018-12-19 Not done, but checking in anyway. Lots left to do, trying to figure out where things go.
    [oresat-zpos-endcap.brd, oresat-zpos-endcap.sch]
2018-12-20 Removed SPS + uC blocks; only magnetometers remain on the end cap. Not great for future expandability, but moves uC to the end card where it's more useful.
    [oresat-zpos-endcap.brd, oresat-zpos-endcap.sch]
2018-12-21 v1.0 done! All components on the inside to protect from The Spaces.
    [oresat-zpos-endcap.brd, oresat-zpos-endcap.sch]
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2018-12-22 Updated outline based on new symmetrical end caps, decreased hole size but kept ground plane back.
    [oresat-zpos-endcap.brd]
2018-12-22 .. .and the -Z end cap. Again, just magnetometers.
    [minusz-end-cap.brd, minusz-end-cap.sch, plusz-end-cap.brd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]
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2019-01-01 Added debug cutout to -Z end cap, and fixed README.
    [minusz-end-cap.brd]
2019-02-25 Added updated keepouts for antennas; opened up helical opening.
    [minusz-end-cap.brd, plusz-end-cap.brd]
2020-08-25 Added first version of OreSat0 end caps, though they are still not fully completed
    [oresat0-minusz-end-cap.brd, oresat0-minusz-end-cap.sch, oresat0-plusz-end-cap.brd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]
2020-08-27 Added connector to backplane. Added NP resistors connecting magnetometer interrupts to i2c buffer alert inputs. Moved traces out of bstop area, and moved components away from the backplane. Changed b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
    [oresat0-minusz-end-cap.brd, oresat0-minusz-end-cap.sch]
2020-08-27 Removed connector cutout from board outline. Increased restrict area for turnstile antenna. Changed some traces to the top layer to avoid the bstop area, and the new restrict area. Added NP resistors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
    [oresat0-plusz-end-cap.brd, oresat0-plusz-end-cap.sch]
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2020-08-28 Moved SCL1 and SDA1 traces to avoid tstop area.
    [oresat0-minusz-end-cap.brd]
2020-08-29 Updated DXF and board outline. Also cleaned up tNames and Bplace layers around backplane connector.
    [oresat0-minusz-end-cap.brd, oresat0-minusz-end-cap.sch]
2020-08-29 Added BOMs and updated attributes for OreSat0 + and - Z end caps.
    [oresat0-minusz-end-cap-bom.xlsx, oresat0-minusz-end-cap.brd, oresat0-minusz-end-cap.sch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]
2020-09-11 Fixed mysterious blank plus z BOM. Also added date and notes fields to minus z BOM.
    [oresat0-minusz-end-cap-bom.xlsx, oresat0-plusz-end-cap-bom.xlsx]
2021-03-28 To begin redoing the +Z end cap board, I took the dimension layer from the 9-10-20 version of the board file and replaced it with the new DXF from Hayden Reinhold.
    [plusz-end-cap.brd]
2021-03-28 I updated the dxf and dimension layers on the oresat 0 +Z end cap board. I also cleared all the DRC errors.
    [oresat0-plusz-end-cap.brd, oresat0-plusz-end-cap.sch]
2021-04-09 New +Z end cap with larger cutout for turnstile.
    New -Z end cap with amazing artwork from Jennifer and thank yous.
    [oresat0-minusz-end-cap.sch, oresat0-plusz-end-cap.brd, oresat0-plusz-end-cap.sch]
2021-10-21 New pretty OreSat0 end cap, now with updated launch provider.
    [oresat0-minusz-end-cap.sch]
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2023-02-06 Clean up directory structure to reflect per-satellite end caps
    [minusz-end-cap.brd, oresat0-minusz-end-cap-bom.xlsx, oresat0-minusz-end-cap.dxf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]
2023-02-12 Renamed to satellite name folders as per other repos
    [minusz-end-cap.kicad_pcb, minusz-end-cap.kicad_sch, plusz-end-cap.kicad_pcb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]
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2023-02-17 Update oresat0.5 plusz end cap file names, and copied oresat0 plusz design, since old 0.5 design was ooooooold
    [oresat0-plusz-end-cap.brd, oresat0.5-plusz-end-cap-bom.xlsx, oresat0.5-plusz-end-cap.kicad_pcb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]
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2023-02-18 Small fixes to oresat0.5 +Z end cap, and added new DXF to -Z cap. Also renamed minusz cap to oresat0.5-minusz
    [oresat0.5-minusz-end-cap.kicad_pcb, oresat0.5-minusz-end-cap.kicad_sch, oresat0.5-plusz-end-cap.kicad_pcb]
2023-02-19 Updated both oresat0.5 end caps. Fixed layout, and added patch antennas
    [oresat0.5-minusz-end-cap.kicad_pcb, oresat0.5-minusz-end-cap.kicad_sch, oresat0.5-plusz-end-cap.kicad_pcb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]
2023-02-19 Updated both OreSat0.5 end caps and cleaned up errors
    [oresat0.5-minusz-end-cap.kicad_pcb, oresat0.5-minusz-end-cap.kicad_sch, oresat0.5-plusz-end-cap.kicad_pcb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]
2023-02-19 OreSat0.5 end caps design review fixes
    [oresat0.5-minusz-end-cap.kicad_pcb, oresat0.5-minusz-end-cap.kicad_sch, oresat0.5-plusz-end-cap.kicad_pcb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]
2023-02-21 Archiving Oresat0 +Z End Cap. Got rid of bad KiCAD import, made PDFs for future use.
    [oresat0-plusz-end-cap.dxf, oresat0-plusz-end-cap.kicad_pcb, oresat0-plusz-end-cap.kicad_sch]
2023-02-21 Updated .gitignore for archive folder, updated readme, and killed old useless eagle file.
    [oresat0-plusz-end-cap.brd]
2023-02-21 Remove unused files; updated PCB with CAM settings.
    [oresat0.5-minusz-end-cap.kicad_pcb]
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2023-02-21 Forgot silkscreen in CAM. Fixed.
    [oresat0.5-plusz-end-cap.kicad_pcb]
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2023-09-15 OreSat0.5 -Z end cap. Updated to latest KiCAD, fixed lack of holes for lens holder, and removed solder mask from around screw heads.
    [oresat0.5-minusz-end-cap.kicad_pcb, oresat0.5-minusz-end-cap.kicad_sch]
2023-09-15 Oresat0.5 +Z End Cap. Still some weird library issues, but skipping for now.
    [oresat0.5-plusz-end-cap.kicad_pcb, oresat0.5-plusz-end-cap.kicad_sch]
2023-12-21 Upgrades OreSat0.5 +Z End Cap to v1.2 -- fits the new deployer, and cleans up a bunch of library issues.
    [oresat0.5-plusz-end-cap.kicad_pcb, oresat0.5-plusz-end-cap.kicad_sch]
2024-02-03 corrected board outline for OreSat 0.5 +z endcap
    [oresat0.5-plusz-end-cap.kicad_pcb]
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2024-03-04 updated mmc5883 magnetometer to mmc5983 for both OreSat 0.5 +Z and -Z endcaps
    [oresat0.5-minusz-end-cap.kicad_pcb, oresat0.5-minusz-end-cap.kicad_sch, oresat0.5-plusz-end-cap.kicad_pcb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]
2024-03-20 moved endcap harwin connectors on both +/-Z endcaps per move in Onshape
    [oresat0.5-minusz-end-cap.kicad_pcb, oresat0.5-minusz-end-cap.kicad_sch, oresat0.5-plusz-end-cap.kicad_pcb]
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2024-03-21 OreSat 0.5 Endcaps (+Z v1.3 and -Z v1.2) ready for ordering, reviewed -Z endcap, made small library and neatness changes to +Z endcap
    [oresat0.5-minusz-end-cap.kicad_pcb, oresat0.5-minusz-end-cap.kicad_sch, oresat0.5-plusz-end-cap.kicad_pcb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]
2024-04-08 Fixed issues 5 and 6 -- weird 4.7k values everywhere, missing libraries, and used no-place to indicate actual no place components.
    [oresat0.5-minusz-end-cap.kicad_pcb, oresat0.5-minusz-end-cap.kicad_sch, oresat0.5-plusz-end-cap.kicad_pcb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]
2024-04-15 Added note on which MAG was which for firmware (PZ1 - MZ2).
    [oresat0.5-minusz-end-cap.kicad_sch, oresat0.5-plusz-end-cap.kicad_sch]
2024-05-06 More information on end cap RF, including coax jumper for end cap.
    [oresat0.5-minusz-end-cap.kicad_sch, oresat0.5-plusz-end-cap.kicad_sch]
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2024-05-08 Fixed BOM.
    [oresat0.5-plusz-end-cap.kicad_pcb, oresat0.5-plusz-end-cap.kicad_sch]
2024-12-12 Added KiCAD 8 import of OreSat0 +Z End Cap v1.1. Still needs lots of work to swich to KiCAD components, and get the schematic/layout synchronized.
    [oresat0-plusz-end-cap.kicad_pcb, oresat0-plusz-end-cap.kicad_sch]
2026-01-26 minus z endcap schematic & pcb w/ PNI rm3100 mag
    Beginning of rework w PNI rm3100
    [oresat1-minusZ-end-cap.kicad_pcb, oresat1-minusZ-end-cap.kicad_sch]
2026-01-31 RM 3100 board layout
    Round 1 - awaiting design review. Some issues with GND pads; DRC is clean, but looks weird. Debating if U1 needs to be further in the corner, therefore change its layout completely.
    [oresat1-minusZ-end-cap.kicad_pcb, oresat1-minusZ-end-cap.kicad_sch]
2026-02-01 Polishing the schematic and layout
    Cleaned up ERCs, lots of OCD polishing for no reason, added 3.3V zone, cleaned up 3.3V routing.
    [oresat1-minusZ-end-cap.kicad_pcb, oresat1-minusZ-end-cap.kicad_sch]
2026-02-01 Fix BOM and add 3D of antenna.
    [oresat1-minusZ-end-cap.kicad_pcb, oresat1-minusZ-end-cap.kicad_sch]
2026-02-05 Plus Z endcap - new dfx and rm3100 magnetometers.
    Routing complete. DRC warnings and errors about the antenna footprint. Labelled pads as unspecified (neither through hole or SMD) and still getting a warning. Other warnings about silkscreen being clipped but didnt want to alter w/o cehckign if that should just be ignored.
    [OreSat 1 +Z End Cap DXF.dxf, oresat1-plusz-end-cap.kicad_pcb, oresat1-plusz-end-cap.kicad_sch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]
2026-02-06 New -Z DFX
    Added new DFX to edge.cuts and User.comments. Antenna footprint warning - juts out over cut.
    [13101.stp, 13104.stp, OreSat1 -Z End Cap DXF.dxf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]
2026-02-12 Added 3D models and fixed fab des
    3D models of antenna patch (-Z) and M55 connector & magIc2 chip on both boards.
    [13156 PNI2gA 162199, MagI2C.step, 13156 PNI2gA 162199, MagI2C.stl, GPS Antenna.step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]
2026-03-11 +Z End Cap ready for fab and assembly.
    Schematic: Made RM3100 symbol better, cleaned up schematic, added variable strings, DRC'd,
    added fiducials
    Layout: Added fiducials, cleaned up polygons, rerouted signals too close to the edge,
    Fixed the connector to the +Z End Card (it was wrong in so many ways), added all the
    3D models to things, fixed the Makefile to use STEP not VRML files, reset the footprint
    libraries Added the correct and latest DXF outline. Removed old DXF and old crusty
    3D and other footprint files. Most important: ADDED KAOMOJI.
    Makefile: Added flag to output STEP file with STP models, not VRML.
    [13156 PNI2gA 162199, MagI2C.step, 13156 PNI2gA 162199, MagI2C.stl, oresat1-plusz-end-cap.dxf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]
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2026-04-10 Update OreSat1 +Z End Cap, but no new build, no substantial change from v1.0, just updated makefile, readme, and some library footprint updates.
    [oresat1-plusz-end-cap.kicad_pcb]
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2026-09-18 Changes to layout
    Aligned some magnetometer coils to align with axis of oresat 1
    [oresat1-minusZ-end-cap.kicad_pcb, oresat1-minusZ-end-cap.kicad_sch, oresat1-plusz-end-cap.kicad_pcb]
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2026-09-24 Added releases, cleaned up PNI inductors, fixed ERCs and DRCs.
    [oresat1-plusz-end-cap.kicad_pcb, oresat1-plusz-end-cap.kicad_sch]
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2026-09-25 Brought -Z end cap up to the current state. Added address resistors, fixed capacitor placement, polished and made PNI layout consistent, added makefile and readme.
    [13101.stp, 13104.stp, oresat1-minusZ-end-cap.kicad_pcb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]
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2026-09-25 Fixed documentation on mag address
    [oresat1-plusz-end-cap.kicad_sch]
2026-09-25 Spelling mistakes and better I2C documentation
    [oresat1-minusZ-end-cap.kicad_sch, oresat1-plusz-end-cap.kicad_pcb, oresat1-plusz-end-cap.kicad_sch]

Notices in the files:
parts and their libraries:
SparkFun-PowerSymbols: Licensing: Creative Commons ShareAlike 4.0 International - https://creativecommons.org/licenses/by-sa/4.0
